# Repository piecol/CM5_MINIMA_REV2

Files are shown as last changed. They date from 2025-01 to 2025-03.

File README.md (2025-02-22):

# CM5 MINIMA REV2

## Introduction

The **CM5 MINIMA REV2** is a compact carrier board for the latest Raspberry Pi computing module 5.
It is designed for embedded applications, DIY electronics, and low-power computing projects. Unlike traditional desktop computers, the CM5 is a small, efficient system that integrates essential computing hardware onto a single board. Whether you're a hobbyist, developer, or engineer, this module provides a versatile platform for various applications, including IoT, automation, and custom hardware development.

If you're not familiar with Raspberry Pi or single-board computers (SBCs), think of the CM5 as a miniaturized computer that can handle tasks like data processing, networking, and hardware control, all while fitting in the palm of your hand. 
https://www.raspberrypi.com/products/compute-module-5/?variant=cm5-104032

Get to know the story behind the MINIMA on Hackster.io:

https://www.hackster.io/piecol/tiny-open-source-media-streamer-with-lorawan-what-a98a93

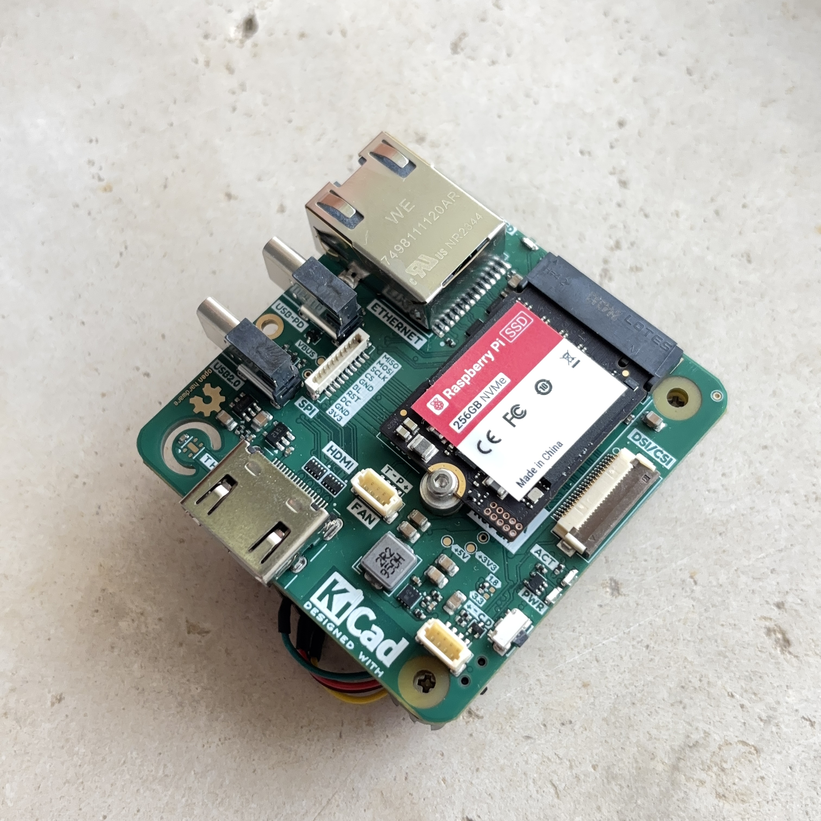
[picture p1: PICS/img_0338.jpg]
PCB_JLC


## Designed with KiCad

MINIMA was developed using KiCad, a powerful open-source Electronic Design Automation (EDA) tool. KiCad enables designers to create high-quality PCB layouts and schematics while maintaining full control over their hardware designs. By leveraging open-source tools like KiCad, the CM5 MINIMA REV2 embraces accessibility, collaboration, and innovation in hardware development.
It is also certified by the Open Source Hardware Association: https://certification.oshwa.org/it000020.html

## Key Features

- **USB-C Power Delivery (PD):** Supports power negotiation for efficient energy use.
- **USB 2.0 Ports:** Connect peripherals such as keyboards, mice, and external storage.
- **Gigabit Ethernet:** High-speed wired networking with a low-profile cutout magjack.
- **HDMI Port:** Output video to external displays for media playback or interface applications.
- **M.2 M Key Slot:** Supports 2230 SSDs for fast storage expansion.
- **CSI/DSI Connector:** Attach camera modules or displays for vision-based applications.
- **SHTC3 Sensirion Sensor:** Built-in temperature and humidity monitoring.
- **I2C Connector (3.3V only):** Connect low-power sensors and communication modules.
- **SPI Connector:** Supports high-speed communication with other devices.
- **Fan Connector:** Optional cooling support for high-performance applications.
- **Status LEDs:** Visual indicators for power and system activity.
- **Compact Size:** Measuring only **5.4 × 5.7 cm**, ideal for space-constrained projects.

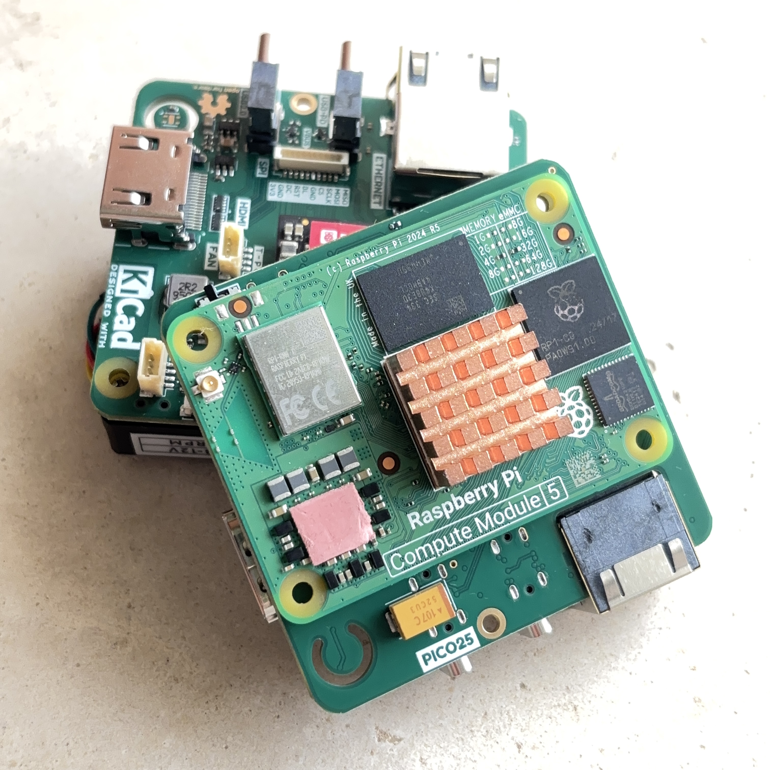
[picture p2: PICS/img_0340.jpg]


## Schematics

[PDF SCHEMATICS](https://github.com/piecol/CM5_MINIMA_REV2/blob/main/CM5_MINIMA_2.pdf)

## Getting Started

To use the **CM5 MINIMA REV2**, you'll need:

- A **USB-C power adapter** that supports Power Delivery (PD).
- A **display (HDMI)** and **input devices (USB keyboard/mouse)** for setup.
- A **network connection** (Ethernet or Wi-Fi via an external adapter if needed).

## Flashing OS

To flash an operating system (OS) to the CM5, use the switch located on the bottom of the board to enable flashing mode. It is equivalent to the "Fit nRPI_BOOT to J2 (disable eMMC Boot) on the IO board jumper." on the CM5 IO board.
Please refere to the official guidelines for further instructions:
https://www.raspberrypi.com/documentation/computers/compute-module.html#set-up-the-io-board

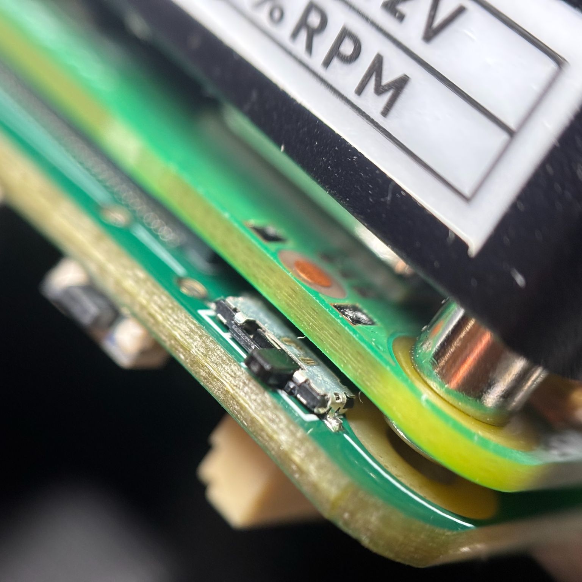
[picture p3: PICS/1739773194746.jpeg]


## Applications

- **IoT & Smart Devices:** Use sensors and network capabilities to create connected applications.
- **Home Automation:** Control and monitor home devices with minimal power consumption.
- **Embedded Systems:** Develop custom hardware solutions for industrial and consumer electronics.
- **Media Centers:** Play videos and manage digital content on an external display.
- **DIY Projects:** Ideal for makers and educators learning about electronics and programming.

## Conclusion

The **CM5 MINIMA REV2** is a powerful and flexible computing module that opens up endless possibilities for embedded computing and automation. Whether you're building a smart device, experimenting with sensors, or designing a networked system, this board provides the essential features you need in a compact, energy-efficient form factor.

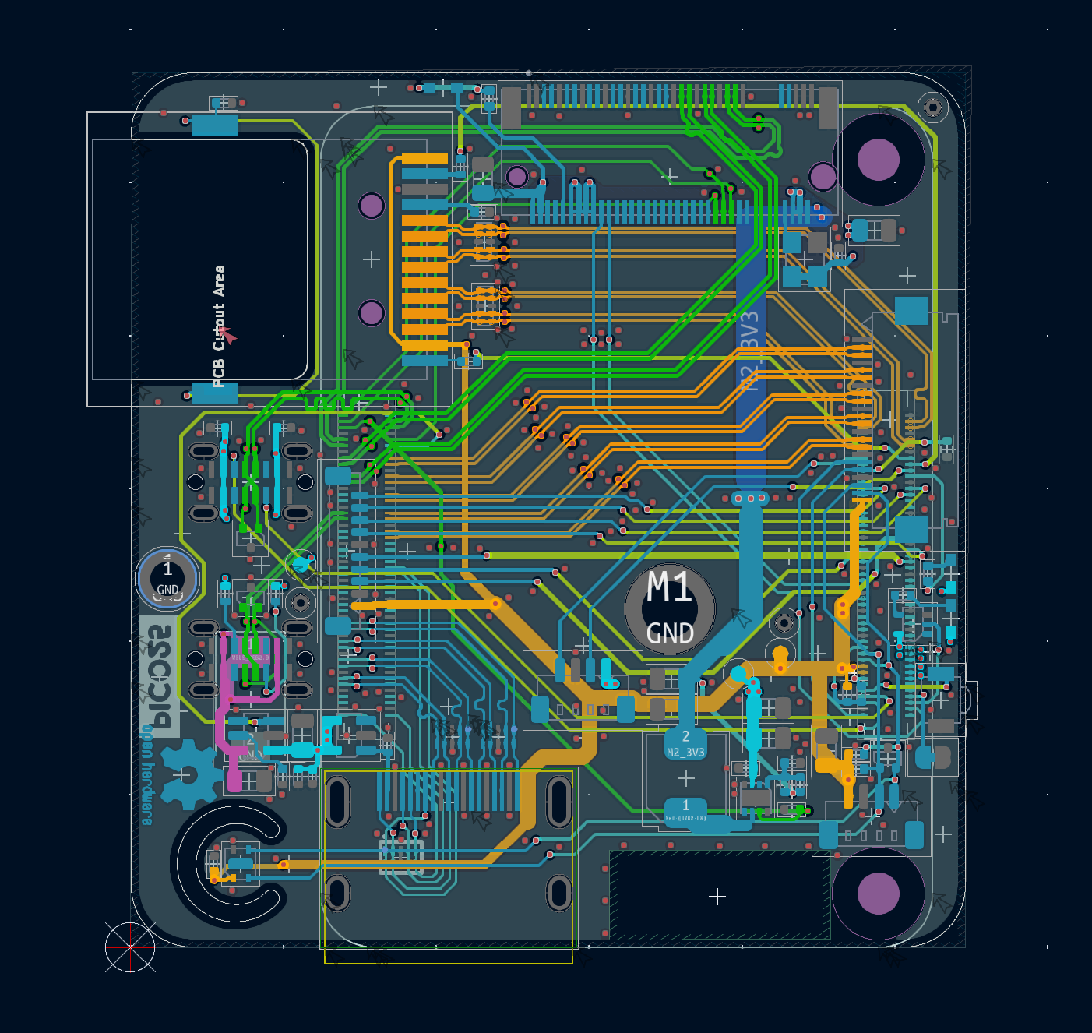
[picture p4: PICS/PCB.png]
PCB


## **Stackup**:
6L (SIG:PWR | GND | SIG-PWR | PWR | GND | SIG:PWR) 

### If you would like to support me:

"Buy Me A Coffee" (https://www.buymeacoffee.com/pierluigicj)

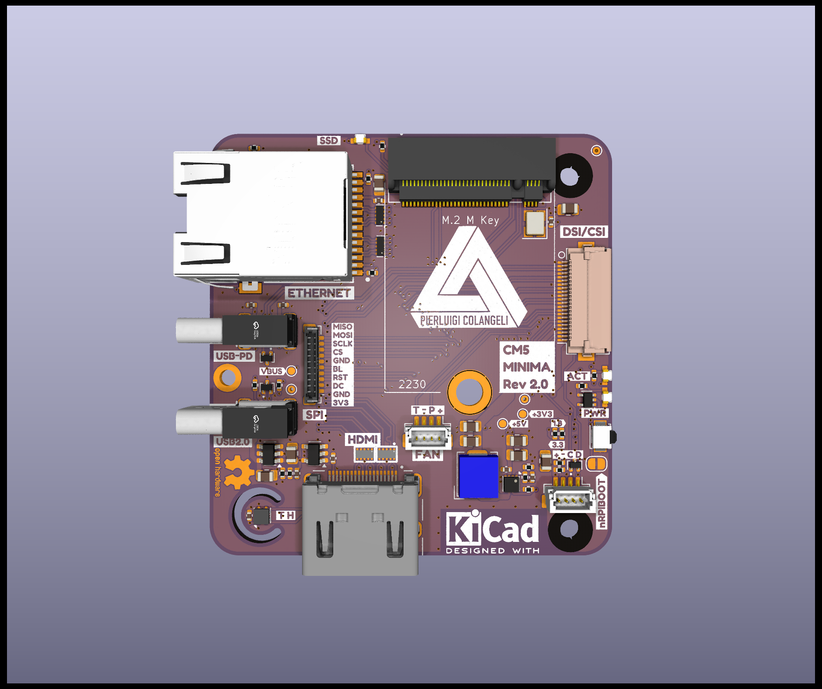
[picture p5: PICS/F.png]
F

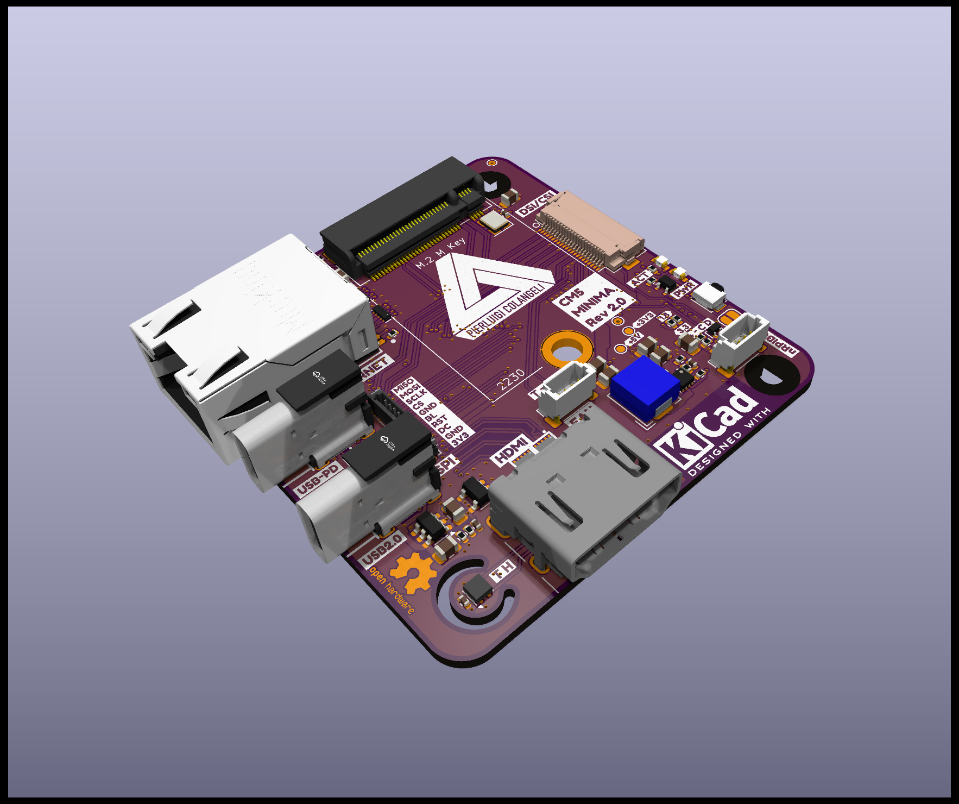
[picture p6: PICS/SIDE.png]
SIDE

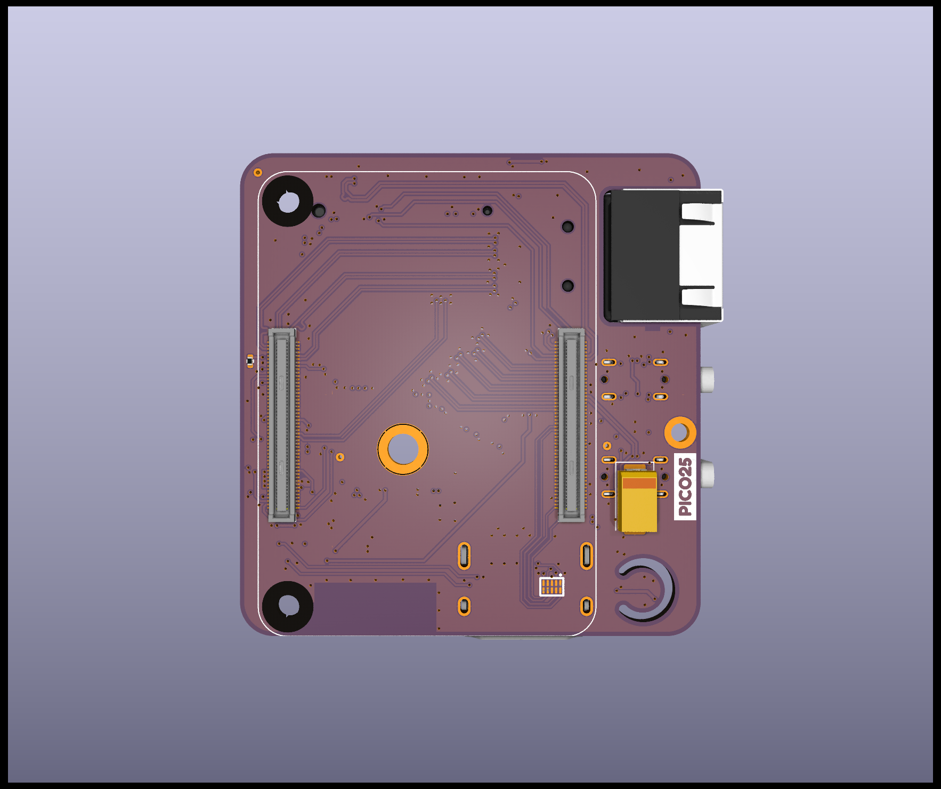
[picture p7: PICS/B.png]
B


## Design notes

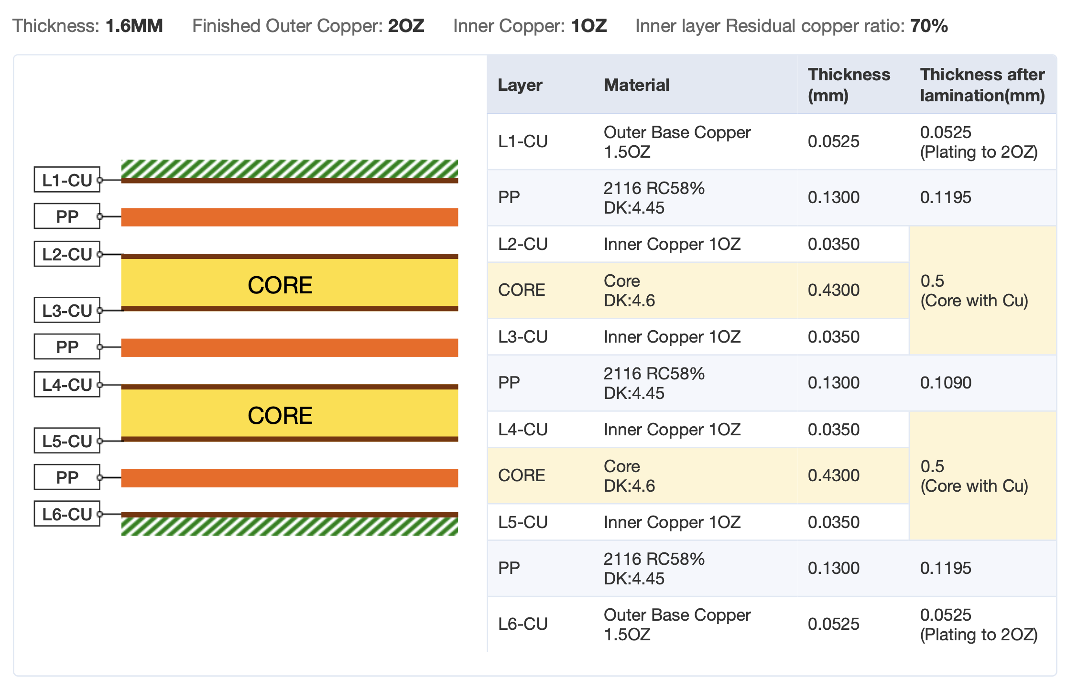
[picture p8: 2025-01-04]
PCBWay_6L_stackup.png

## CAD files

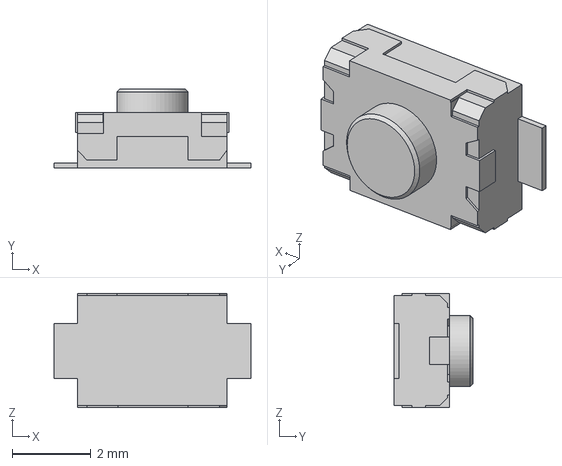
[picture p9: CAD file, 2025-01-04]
3d_lib/3x4x2 tact button.step
5.00 x 2.00 x 2.90 mm

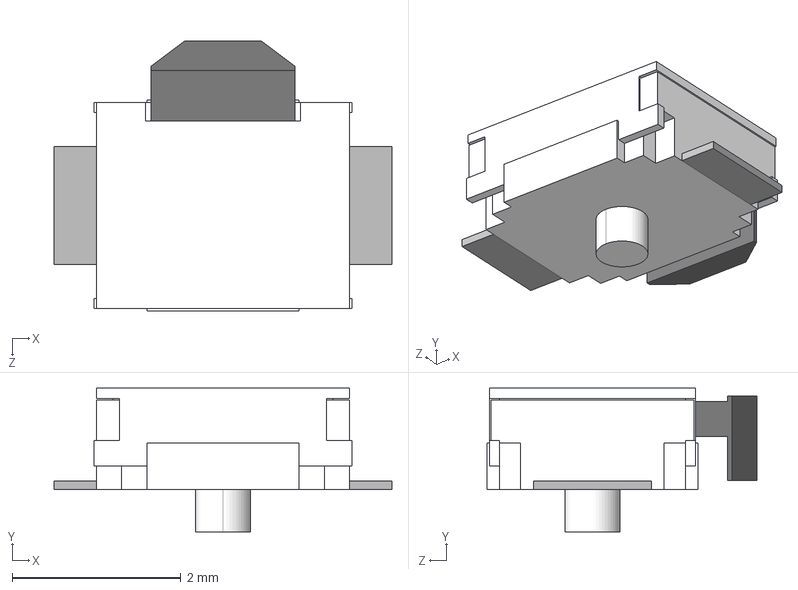
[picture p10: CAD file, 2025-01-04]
3d_lib/LIB_B3U-3000PM-B/B3U-3000PM-B/3D/B3U-3000PM-B.stp
4.00 x 1.70 x 3.20 mm

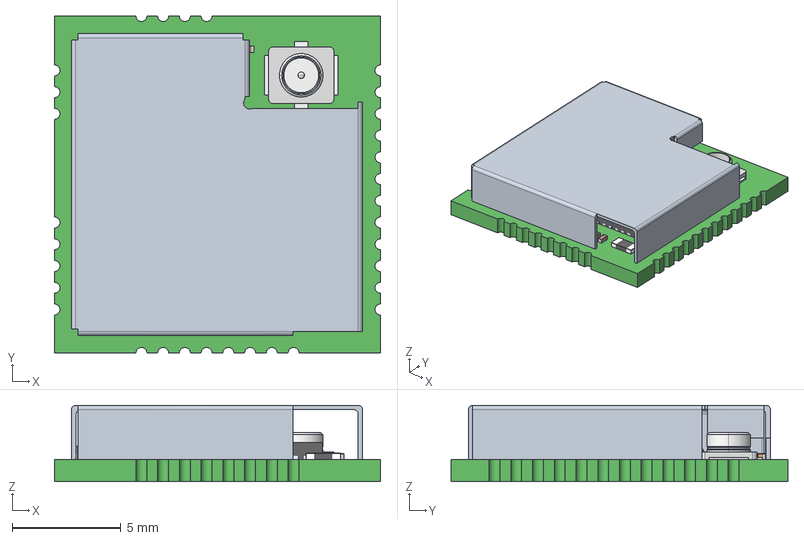
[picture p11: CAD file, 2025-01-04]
3d_lib/RAK3172--3DModel-STEP-100311.STEP
15.0 x 15.5 x 3.51 mm
0201_SMD_Capacitor x 36
Extruded
R0201 x 7
RES_1005-0402 x 3
QFN48_7x7
NT2016SA
C0402 x 4
crystal_rtf2012
D030A-そ敖裔

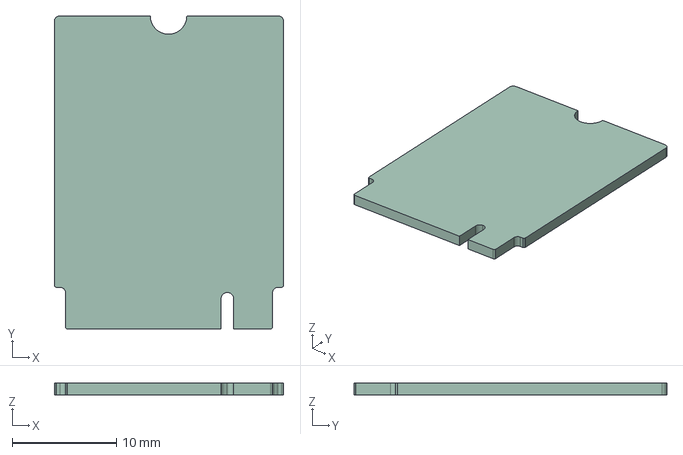
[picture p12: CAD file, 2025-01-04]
3d_lib/M.2-B.step
22.0 x 30.1 x 1.20 mm

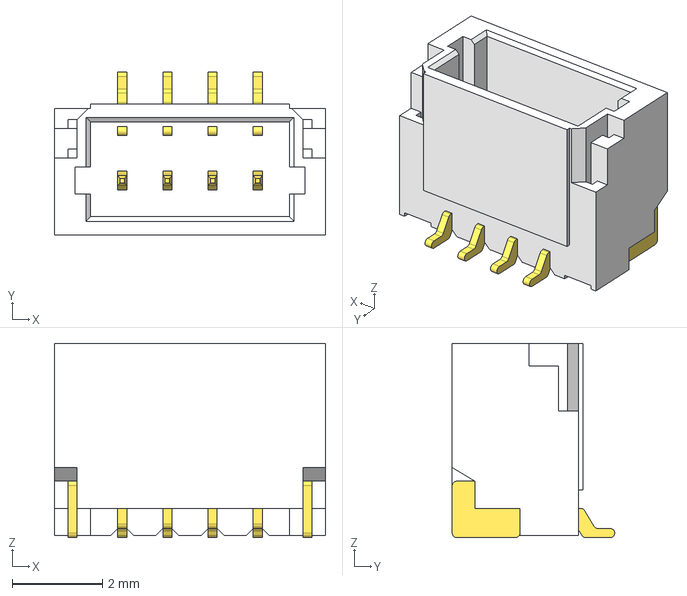
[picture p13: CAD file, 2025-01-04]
3d_lib/BM4B-SRSS-TB.step
6.00 x 3.60 x 4.30 mm

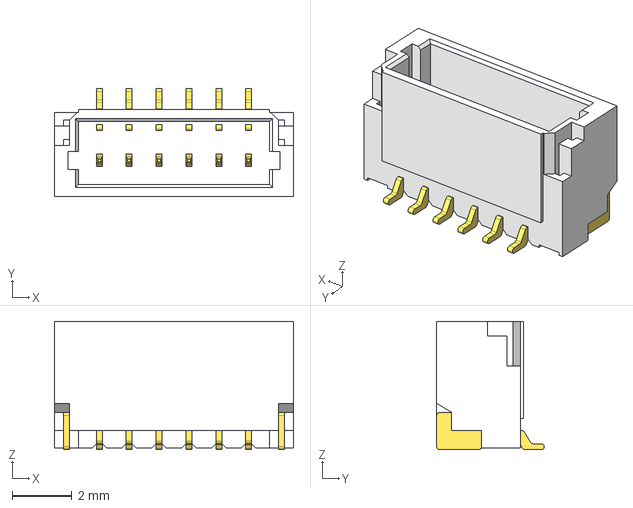
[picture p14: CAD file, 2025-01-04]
3d_lib/BM6B-SRSS-TB.step
8.00 x 3.60 x 4.30 mm

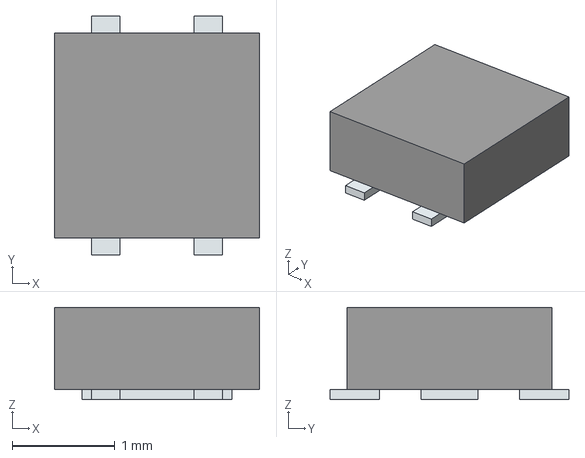
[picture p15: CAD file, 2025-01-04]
3d_lib/SHTC3-TR-10KS.stp
2.00 x 2.33 x 0.9 mm
Pins

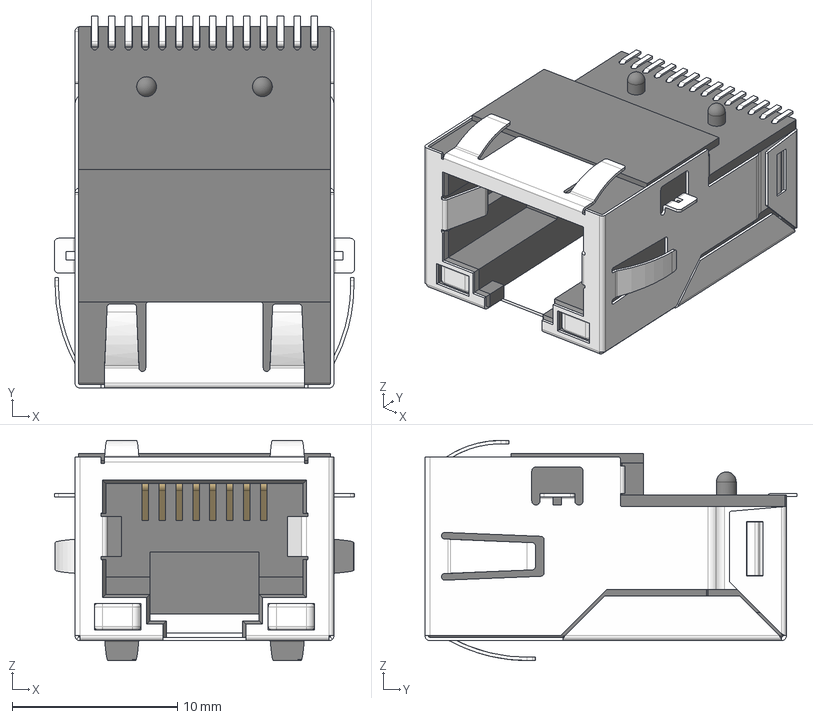
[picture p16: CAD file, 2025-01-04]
3d_lib/WE-RJ45LAN-7498111120AR (rev1).stp
18.1 x 22.5 x 13.3 mm
Shielding
Insulator x 3

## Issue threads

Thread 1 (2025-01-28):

PoE capabilities

jainavgohel, 2025-01-28:
Love this project, would be cool to see this support power over Ethernet so only one cable was needed for testing. This would cost a bit of board size but would be worth it to not need a second cable.

Additionally with PoE functionality it would make for a very appealing board in the home lab 10 in rack space.

piecol, 2025-01-28:
Thanks,

I'll consider the PoE, it's indeed a cool feature!

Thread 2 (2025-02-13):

HDMI Power-on Glitch

manuel-imboden, 2025-02-13:
Hi Pier

As discussed via email, I'm opening an issue so you can track this for a future revision:

When a HDMI monitor is connected, the MINIMA refuses to boot up again after booting once and shutting it down. As you have observed, this glitch is also present with Raspberry Pi I/O board and I have found at least one [report of a similar issue](https://forums.raspberrypi.com/viewtopic.php?t=381325).

In my testing, it only happened when the monitor and the MINIMA are on different power supplies (a wall adapter and a power bank for example) and when I am using a non-e-marked cable to power the MINIMA. Using a TB3 cable made the glitch disappear.

The reason remains elusive to me. Might be a capacitance problem as you have suggested, or something like a ground voltage offset that causes some reverse current to flow through the HDMI and triggers some protection.

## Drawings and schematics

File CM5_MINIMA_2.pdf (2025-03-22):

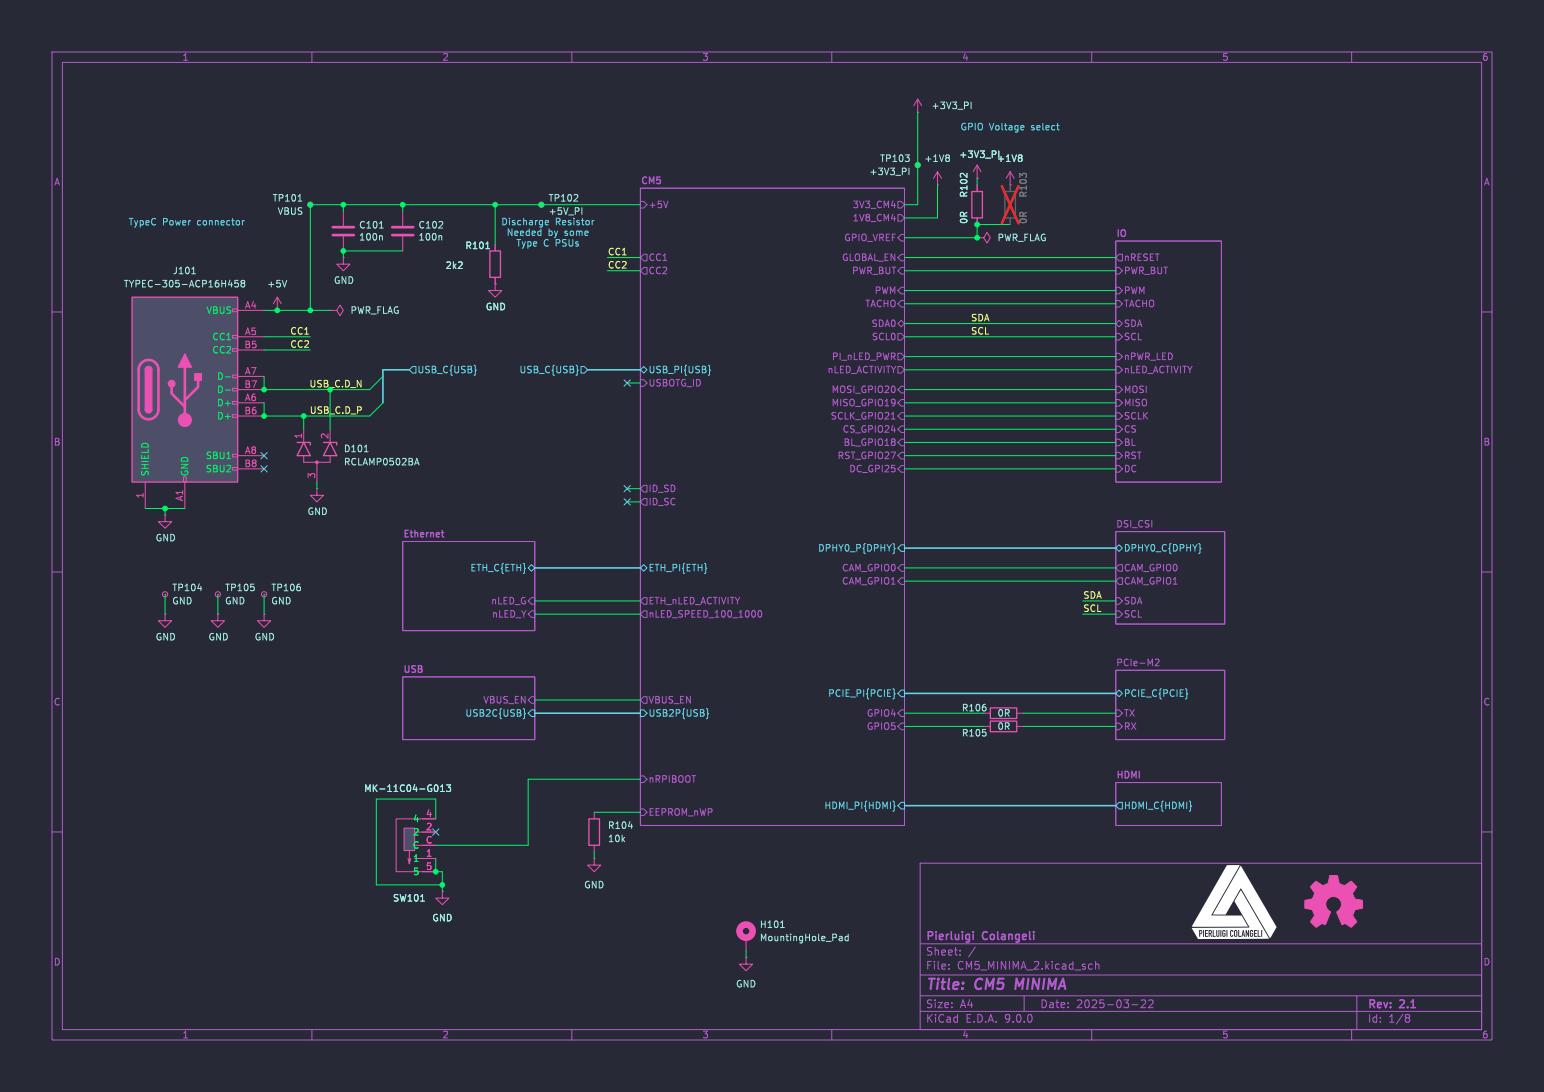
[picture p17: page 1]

PCIE_C{PCIE} PCIe-M2 HDMI_C{HDMI} HDMI USB_PI{USB} USBOTG_ID

SCL SDA DPHY0_C{DPHY} CAM_GPIO0 CAM_GPIO1 DSI_CSI ETH_C{ETH} nLED_Y

File: CM5_MINIMA_2.kicad_sch Sheet: / Pierluigi Colangeli

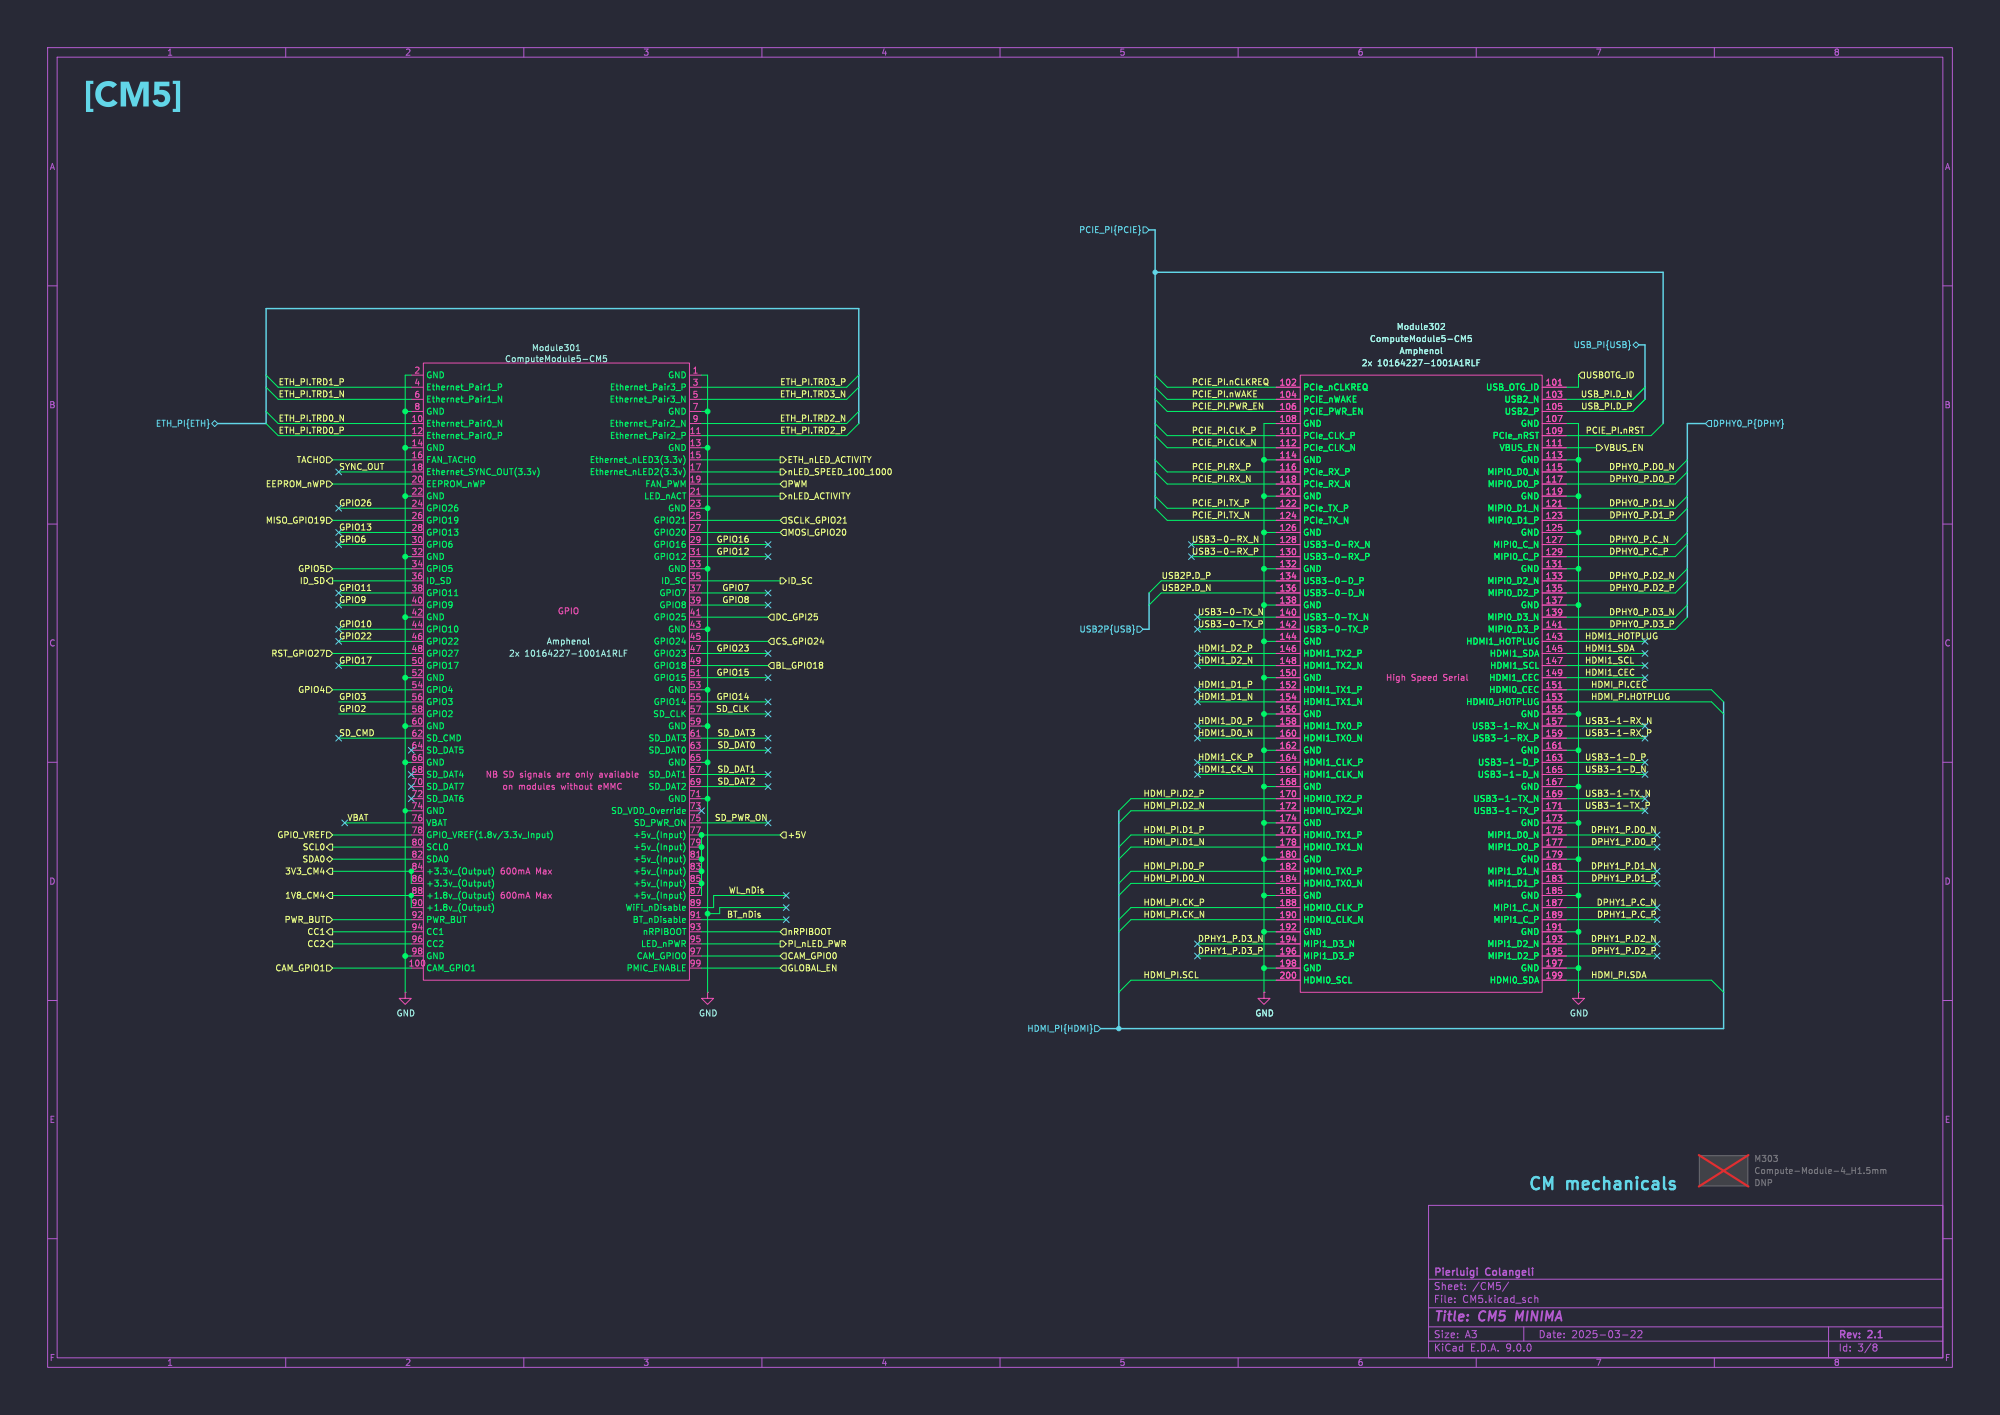
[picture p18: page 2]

GND 2 Ethernet_Pair1_P 4 Ethernet_Pair1_N 6 GND 8 Ethernet_Pair0_N 10 Ethernet_Pair0_P 12 GND 14 FAN_TACHO 16 Ethernet_SYNC_OUT(3.3v) 18 EEPROM_nWP 20 GND 22 GPIO26 24 GPIO19 26 GPIO13 28 GPIO6 30 GND 32 GPIO5 34
ID_SD 36 GPIO11 38 GPIO9 40 GND 42 GPIO10 44 GPIO22 46 GPIO27 48 GPIO17 50 GND 52 GPIO4 54 GPIO3 56 GPIO2 58 GND 60 SD_CMD 62 SD_DAT5 64 GND 66 SD_DAT4 68 SD_DAT7 70 SD_DAT6 72 GND 74 VBAT 76 GPIO_VREF(1.8v/3.3v_Input) 78 SCL0 80 SDA0 82 +3.3v_(Output) 84 +3.3v_(Output) 86 +1.8v_(Output) 88 +1.8v_(Output) 90 PWR_BUT 92 CC1 94 CC2 96 GND 98 CAM_GPIO1 100

on modules without eMMC GPIO

600mA Max 600mA Max NB SD signals are only available

File: CM5.kicad_sch Sheet: /CM5/ Pierluigi Colangeli

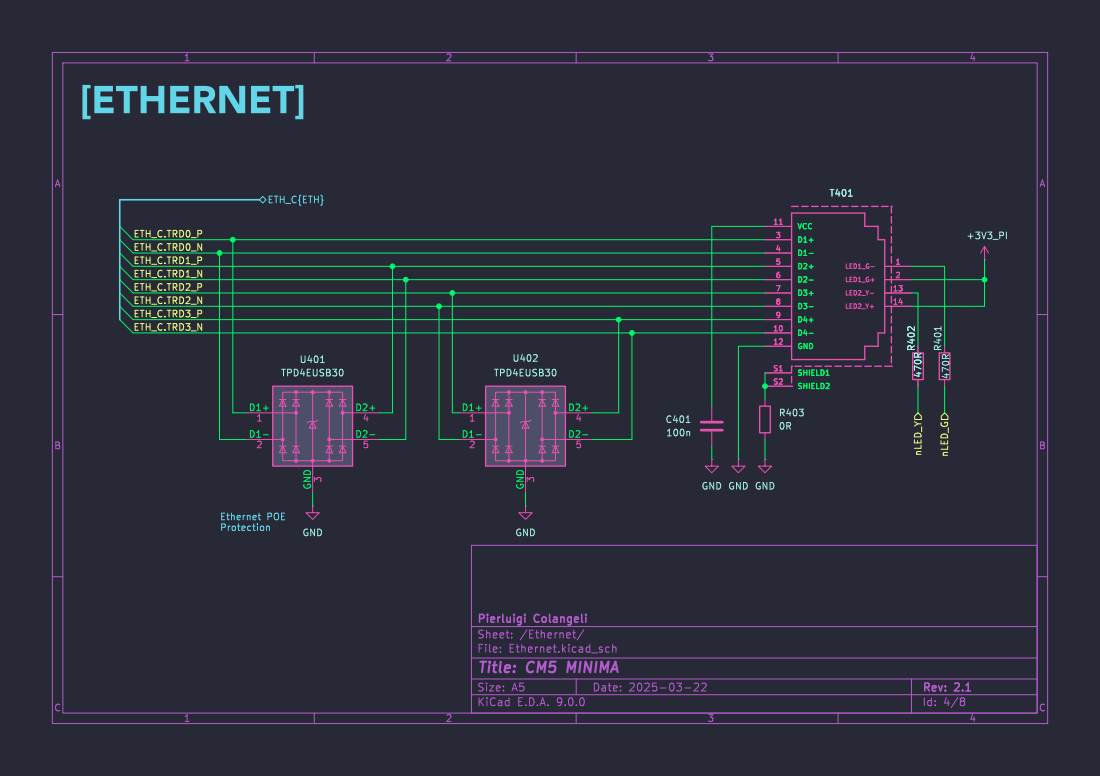
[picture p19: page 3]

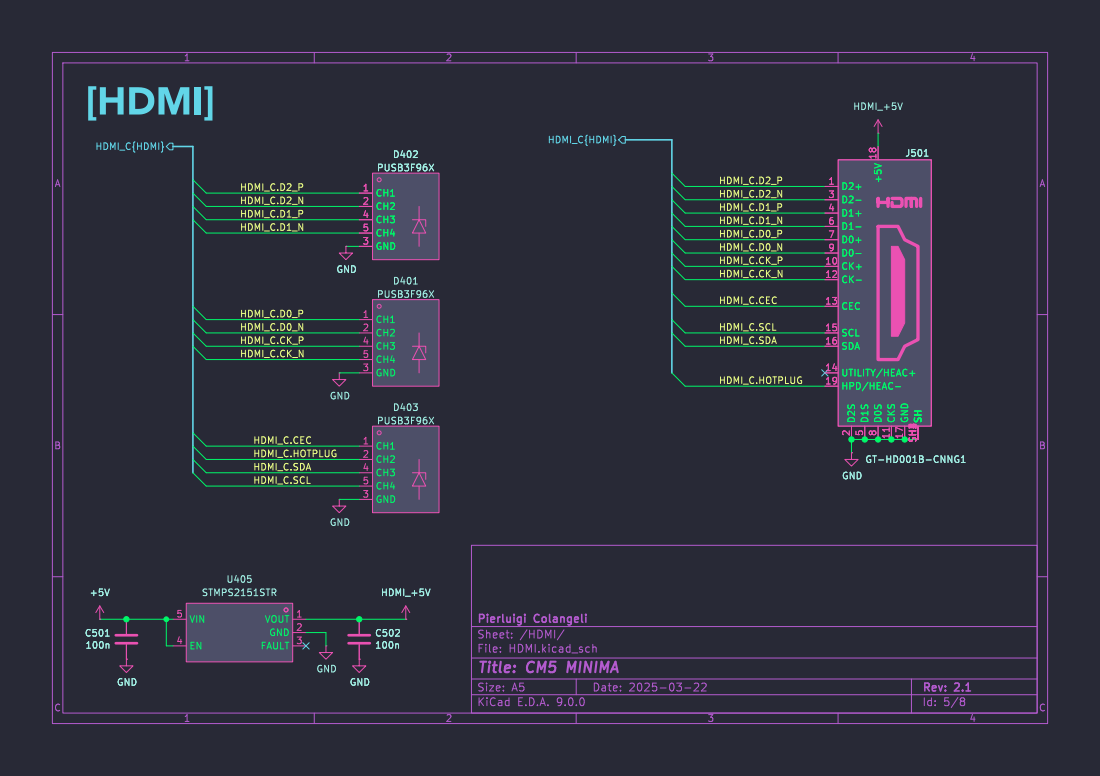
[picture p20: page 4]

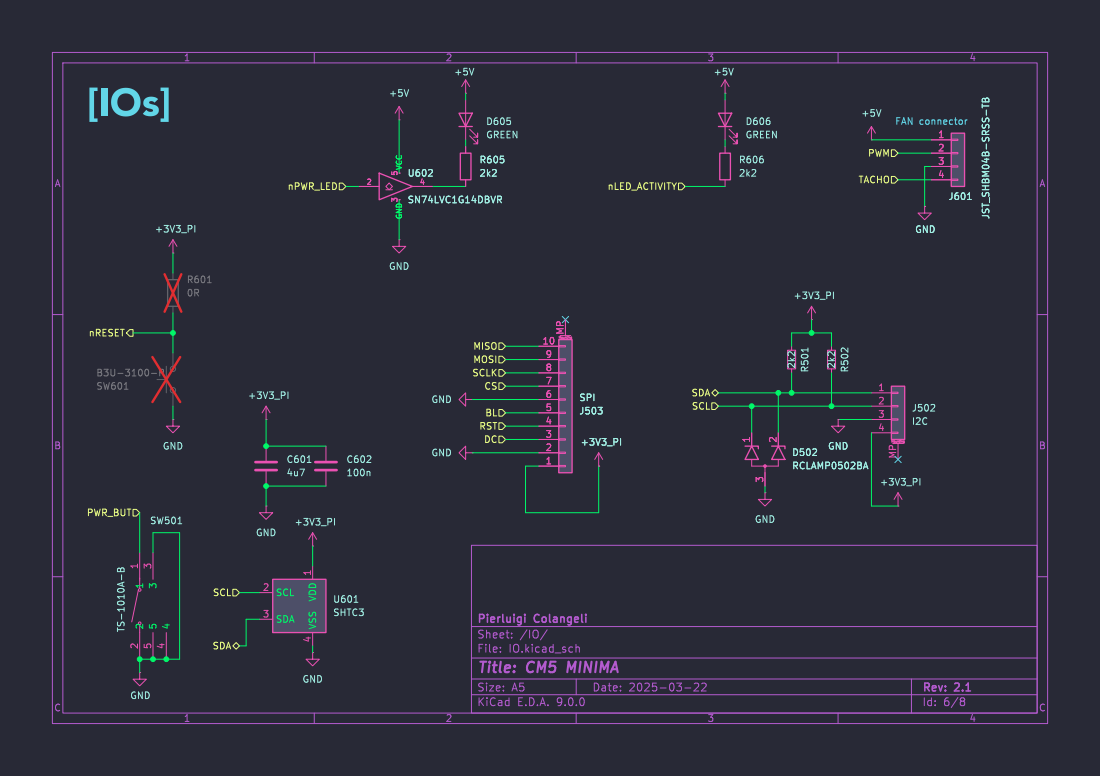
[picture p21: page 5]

2 | Mounting 1

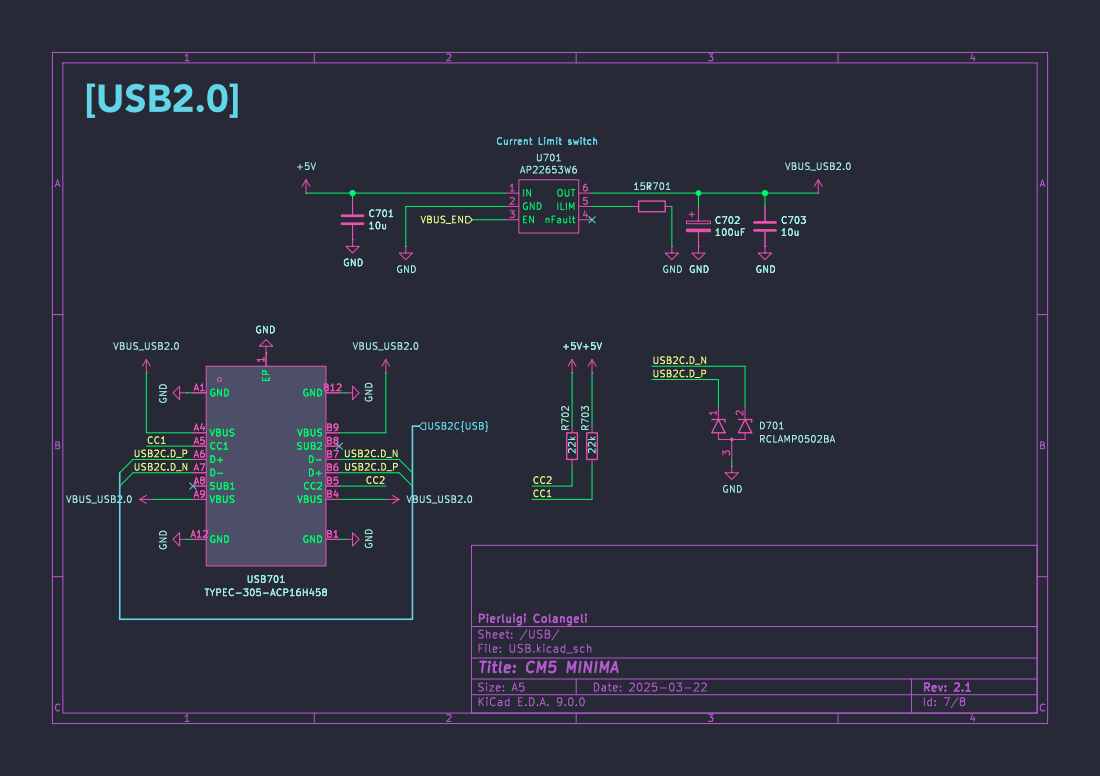
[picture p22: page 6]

File: USB.kicad_sch Sheet: /USB/ Pierluigi Colangeli C701
USB2C{USB} VBUS_EN
10uGND

1 GNDB12 VBUS B9 SUB2 B8 D- B7 D+ B6 CC2 B5 VBUS B4 GND B1 GND

1 GNDB12 VBUS B9 SUB2 B8 D- B7 D+ B6 CC2 B5 VBUS B4 GND B1 USB701 TYPEC-305-ACP16H458

2 D701 RCLAMP0502BA GND GND GND GND

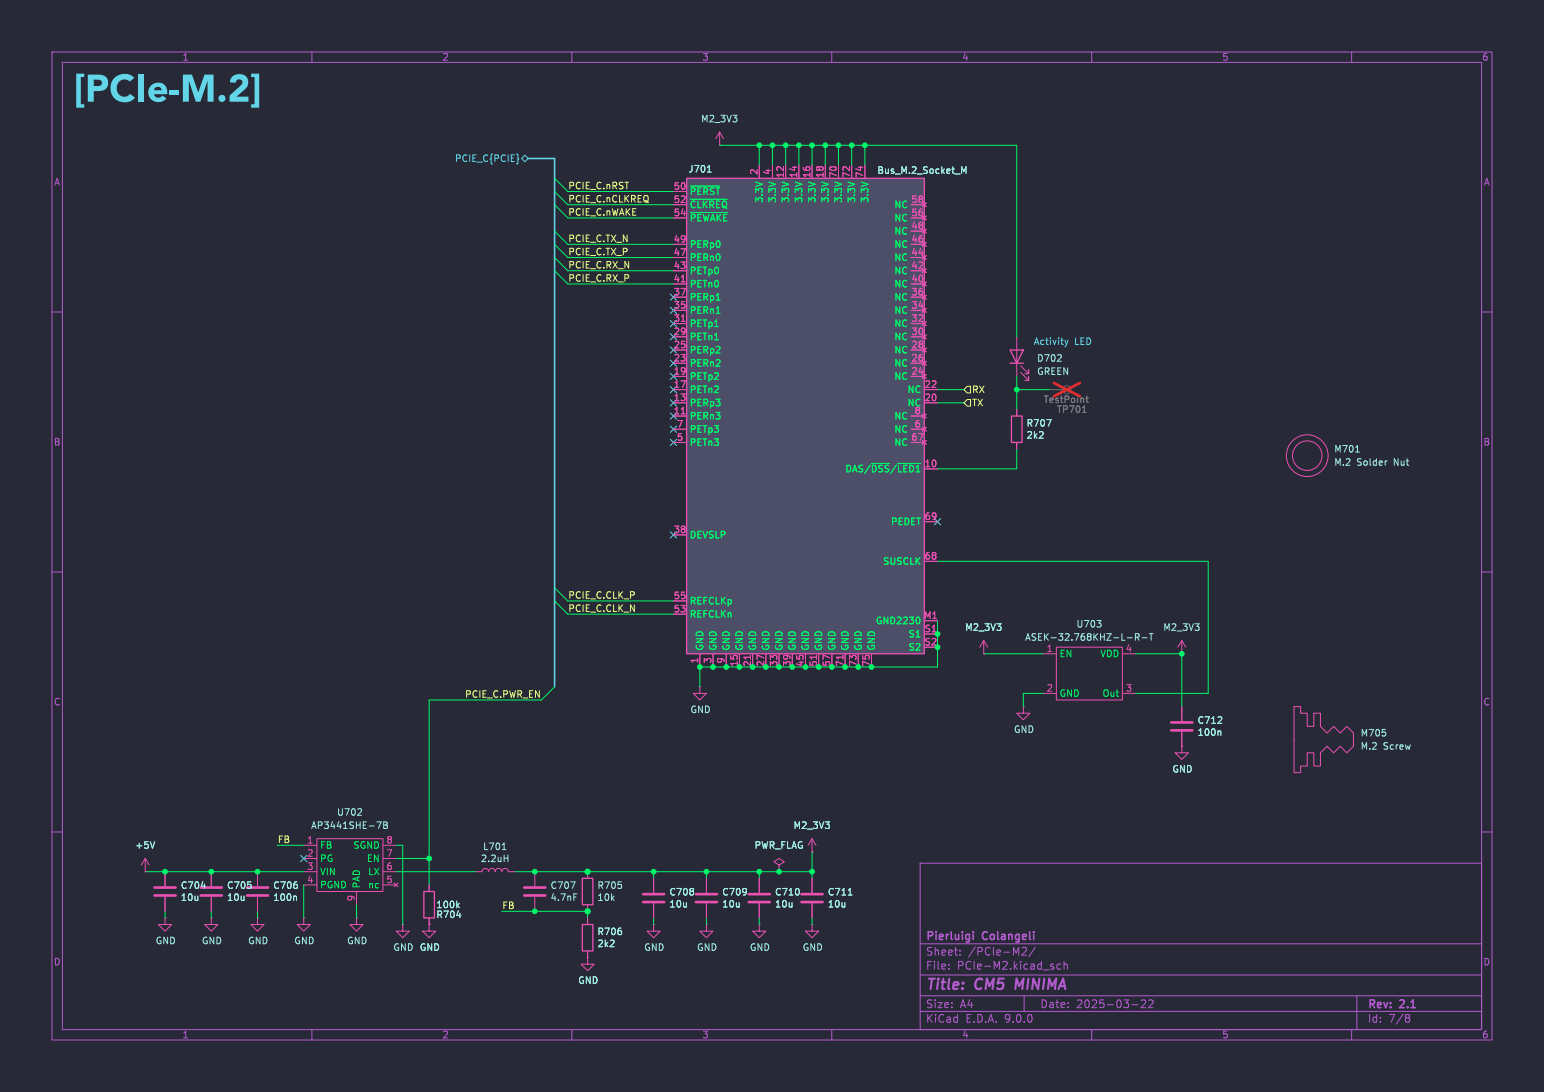
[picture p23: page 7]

4 GND 33 3.3V 12 GND 39 3.3V 14 GND 45 3.3V 16 GND 51 3.3V 18 GND 57 3.3V 70 GND 71 3.3V 72 GND 73 3.3V 74 GND 75 NC 58 NC 56 NC 48 NC 46 NC 44 NC 42 NC 40 NC 36 NC 34 NC 32 NC 30 NC 28 NC 26 NC 24 NC 8 NC 6 NC 67 NC 22 NC 20 DAS/~{DSS}/~{LED1} 10 PEDET 69 SUSCLK 68 GND2230 M1 S1 S1 S2 S2 C704

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

File: PCIe-M2.kicad_sch Sheet: /PCIe-M2/ Pierluigi Colangeli GND

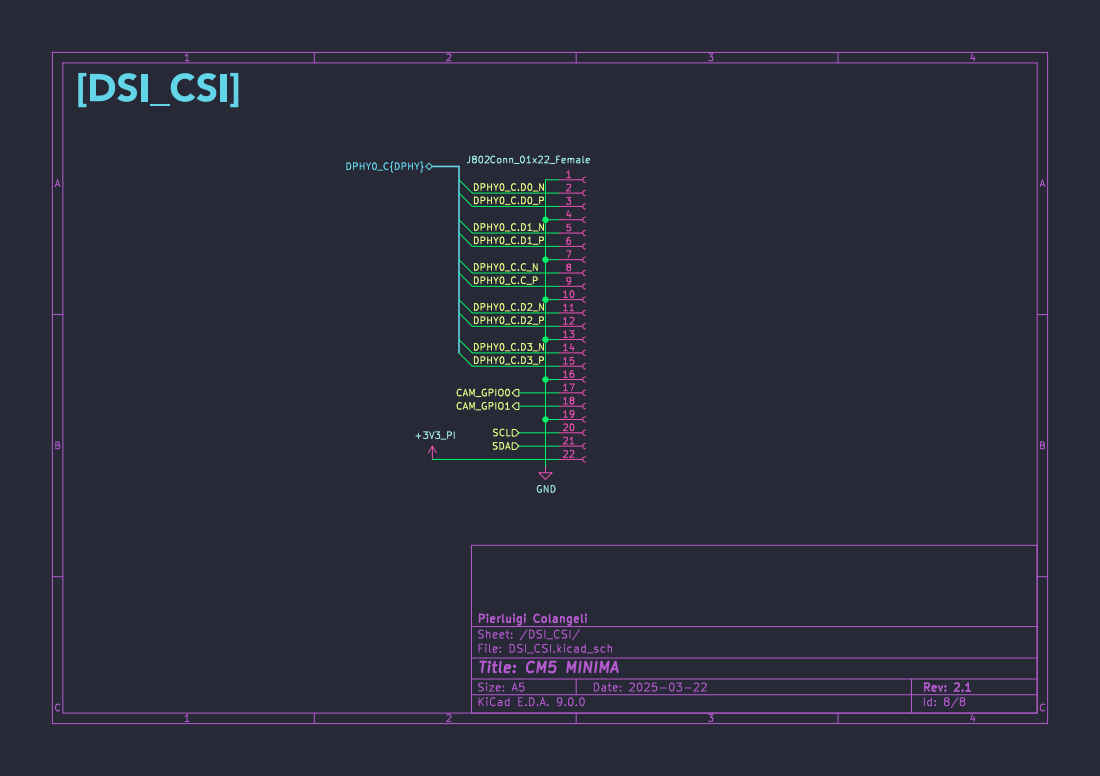
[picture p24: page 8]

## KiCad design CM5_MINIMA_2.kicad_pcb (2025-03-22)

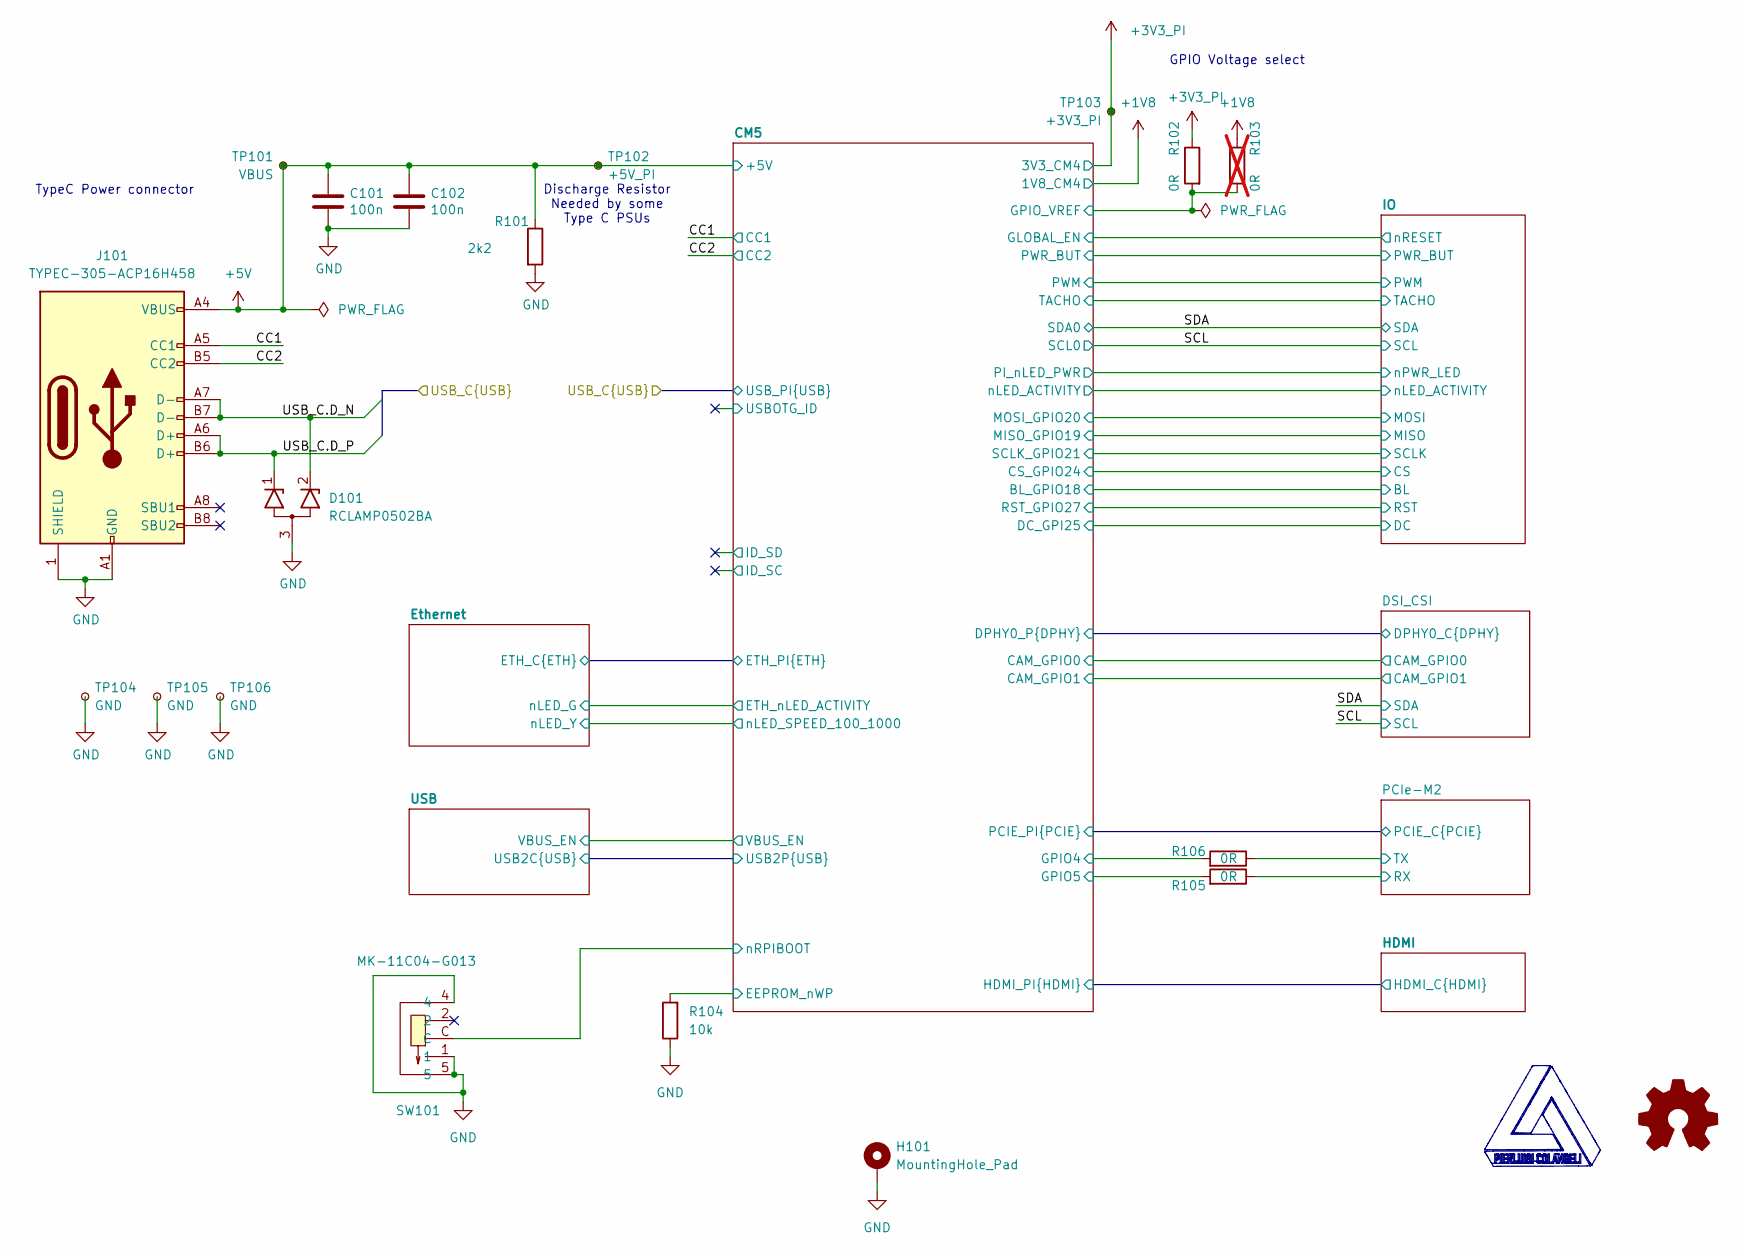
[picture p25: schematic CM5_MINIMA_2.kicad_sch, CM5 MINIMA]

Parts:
C101, C102: 100n; C_0402_1005Metric; Part Description 0.1uF 10% 16V Ceramic Capacitor X7R 040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
D101: RCLAMP0502BA; SOT-416
H101: MountingHole_Pad; MountingHole_2.2mm_M2_DIN965_Pad_TopBottom
J101: TYPEC-305-ACP16H458; USB-C-SMD_TYPEC-305-ACP16H458; Part Description USBC USB2 data and power connector
R101: 2k2; R_0402_1005Metric
R102, R105, R106: 0R; R_0402_1005Metric; Part Description Resistor 0R M2012 5%
R103: 0R; R_0402_1005Metric; not fitted
R104: 10k; R_0402_1005Metric
SW101: MK-11C04-G013; SW-SMD_MK-11C04-G013; LCSC Part C778185
TP101: VBUS; TestPoint_Pad_D1.0mm
TP102: +5V_PI; TestPoint_Pad_D1.0mm
TP103: +3V3_PI; TestPoint_Pad_D1.0mm
TP104, TP105, TP106: GND; TestPoint_THTPad_D1.0mm_Drill0.5mm

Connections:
+1V8: R103.1; also elsewhere on the board
+3V3_PI: R102.1, TP103.1; also elsewhere on the board
+5V: C101.1, C102.1, J101.A4 (VBUS), J101.A9 (VBUS), J101.B4 (VBUS), J101.B9 (VBUS), R101.1, TP101.1, TP102.1; also elsewhere on the board
/CC1: J101.A5 (CC1); also elsewhere on the board
/CC2: J101.B5 (CC2); also elsewhere on the board
/CM5/EEPROM_nWP: R104.2; also elsewhere on the board
/CM5/GPIO4: R106.2; also elsewhere on the board
/CM5/GPIO5: R105.2; also elsewhere on the board
/CM5/GPIO_VREF: R102.2, R103.2; also elsewhere on the board
/CM5/nRPIBOOT: SW101.C; also elsewhere on the board
/PCIe-M2/RX: R105.1; also elsewhere on the board
/PCIe-M2/TX: R106.1; also elsewhere on the board
/USB_C.D_N: D101.2 (K2), J101.A7 (D-), J101.B7 (D-); also elsewhere on the board
/USB_C.D_P: D101.1 (K1), J101.A6 (D+), J101.B6 (D+); also elsewhere on the board
GND: C101.2, C102.2, D101.3 (A), H101.1, J101.1 (SHIELD), J101.A1 (GND), J101.A12 (GND), J101.B1 (GND), J101.B12 (GND), R101.2, R104.1, SW101.1, SW101.4, SW101.5, TP104.1, TP105.1, TP106.1; also elsewhere on the board

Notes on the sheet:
GPIO Voltage select
TypeC Power connector
Discharge Resistor Needed by some Type C PSUs

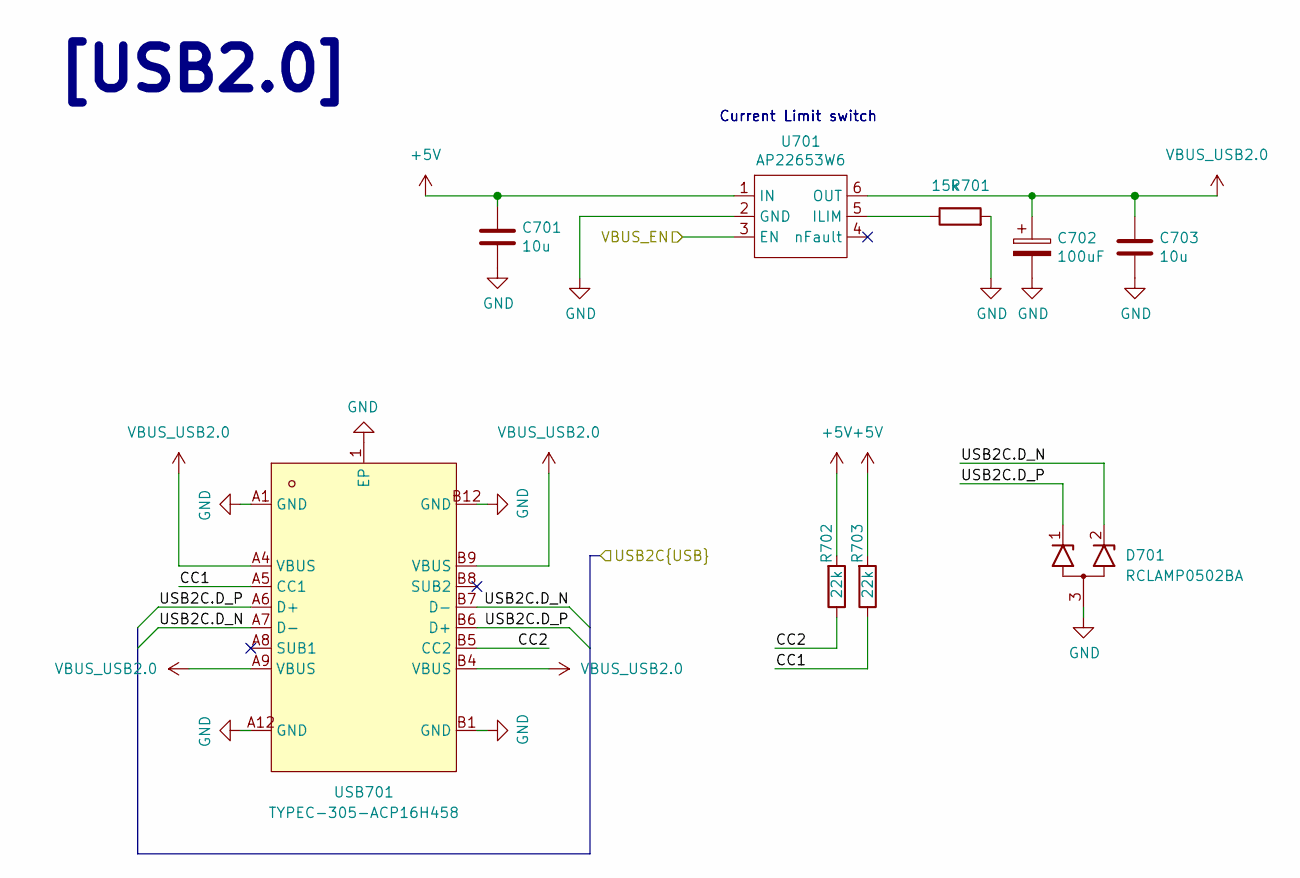
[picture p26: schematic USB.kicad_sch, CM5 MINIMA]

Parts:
C701, C703: 10u; C_0805_2012Metric; Part Description 10uF 10% 10V Ceramic Capacitor X7R 0805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
C702: 100uF; CP_EIA-7343-31_Kemet-D; Part Description Capacitor, SP-Cap, 100u, 6.3V, 15mR ESR
D701: RCLAMP0502BA; SOT-416
R701: 15k; R_0402_1005Metric; Part Description Resistor 15K M1005 1% 63mW
R702, R703: 22k; R_0402_1005Metric
U701: AP22653W6; SOT-23-6; Part Description Power Switch/Driver 1:1 P-Channel 2.1A 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
USB701: TYPEC-305-ACP16H458; USB-C-SMD_TYPEC-305-ACP16H458; LCSC Part C5454943

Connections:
+5V: C701.1, R702.2, R703.2, U701.1 (IN); also elsewhere on the board
/CM5/USB2P.D_N: D701.2 (K2), USB701.A7 (D-), USB701.B7 (D-); also elsewhere on the board
/CM5/USB2P.D_P: D701.1 (K1), USB701.A6 (D+), USB701.B6 (D+); also elsewhere on the board
/CM5/VBUS_EN: U701.3 (EN); also elsewhere on the board
/USB/CC1: R703.1, USB701.A5 (CC1)
/USB/CC2: R702.1, USB701.B5 (CC2)
GND: C701.2, C702.2, C703.2, D701.3 (A), R701.2, U701.2 (GND), USB701.1 (EP), USB701.A1 (GND), USB701.A12 (GND), USB701.B1 (GND), USB701.B12 (GND); also elsewhere on the board
unnamed: R701.1, U701.5 (ILIM)
VBUS_USB2.0: C702.1, C703.1, U701.6 (OUT), USB701.A4 (VBUS), USB701.A9 (VBUS), USB701.B4 (VBUS), USB701.B9 (VBUS)

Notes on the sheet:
[USB2.0]
Current Limit switch

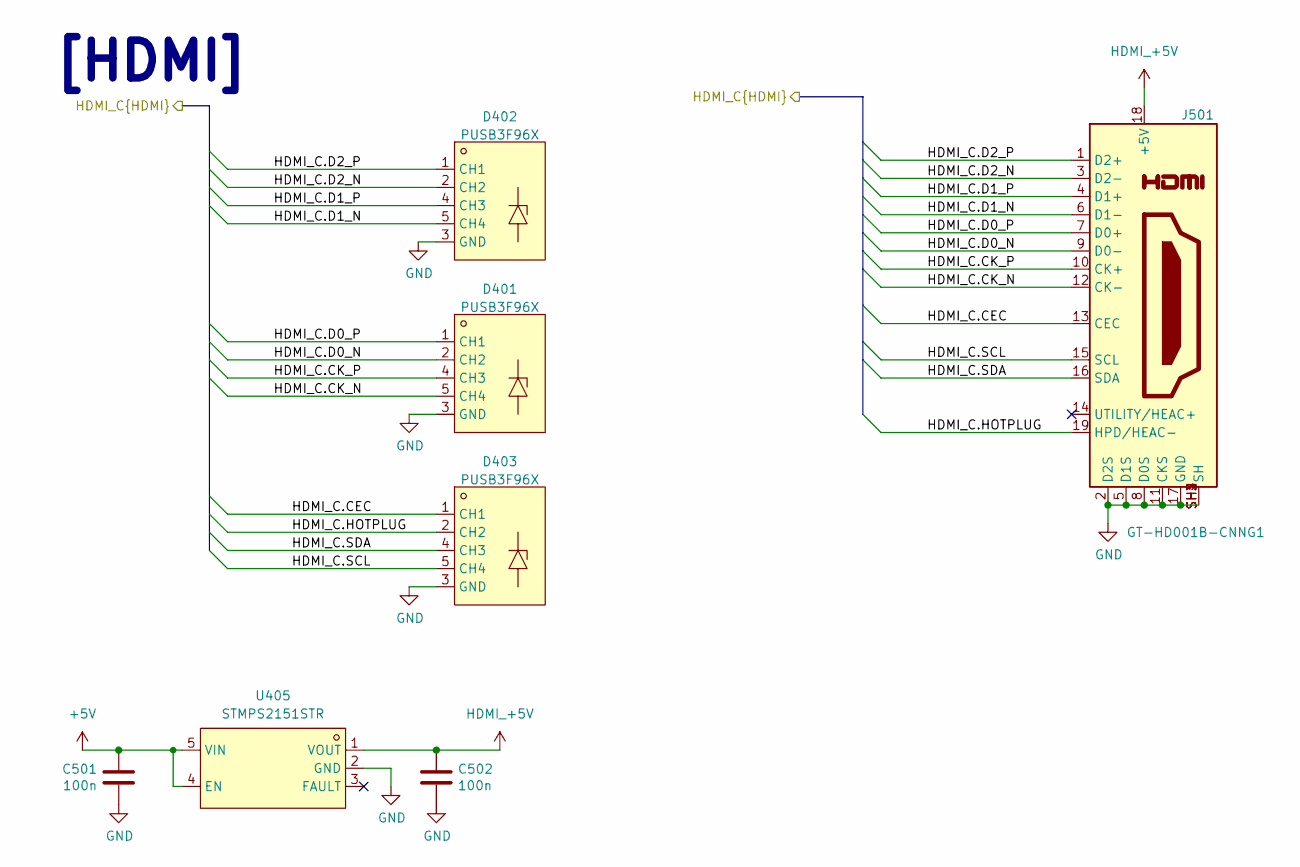
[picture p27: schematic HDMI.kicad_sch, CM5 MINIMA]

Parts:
C501, C502: 100n; C_0402_1005Metric; Part Description 0.1uF 10% 16V Ceramic Capacitor X7R 040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
D401, D402, D403: PUSB3F96X; DFN2510A-10_L2.5-W1.0-P0.50-BL; LCSC Part C478121
J501: GT-HD001B-CNNG1; EDAC 690-019-298-412; Part Description HDMI Connector, Right Angle, 19 Contact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
U405: STMPS2151STR; SOT-23-5; LCSC Part C135998

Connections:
+5V: C501.1, U405.4 (EN), U405.5 (VIN); also elsewhere on the board
/CM5/HDMI_PI.CEC: D403.1 (CH1), D403.10 (NC), J501.13 (CEC); also elsewhere on the board
/CM5/HDMI_PI.CK_N: D401.5 (CH4), D401.6 (NC), J501.12 (CK-); also elsewhere on the board
/CM5/HDMI_PI.CK_P: D401.4 (CH3), D401.7 (NC), J501.10 (CK+); also elsewhere on the board
/CM5/HDMI_PI.D0_N: D401.2 (CH2), D401.9 (NC), J501.9 (D0-); also elsewhere on the board
/CM5/HDMI_PI.D0_P: D401.1 (CH1), D401.10 (NC), J501.7 (D0+); also elsewhere on the board
/CM5/HDMI_PI.D1_N: D402.5 (CH4), D402.6 (NC), J501.6 (D1-); also elsewhere on the board
/CM5/HDMI_PI.D1_P: D402.4 (CH3), D402.7 (NC), J501.4 (D1+); also elsewhere on the board
/CM5/HDMI_PI.D2_N: D402.2 (CH2), D402.9 (NC), J501.3 (D2-); also elsewhere on the board
/CM5/HDMI_PI.D2_P: D402.1 (CH1), D402.10 (NC), J501.1 (D2+); also elsewhere on the board
/CM5/HDMI_PI.HOTPLUG: D403.2 (CH2), D403.9 (NC), J501.19 (HPD/HEAC-); also elsewhere on the board
/CM5/HDMI_PI.SCL: D403.5 (CH4), D403.6 (NC), J501.15 (SCL); also elsewhere on the board
/CM5/HDMI_PI.SDA: D403.4 (CH3), D403.7 (NC), J501.16 (SDA); also elsewhere on the board
GND: C501.2, C502.2, D401.3 (GND), D401.8 (GND), D402.3 (GND), D402.8 (GND), D403.3 (GND), D403.8 (GND), J501.2 (D2S), J501.5 (D1S), J501.8 (D0S), J501.11 (CKS), J501.17 (GND), J501.SH1 (SH), J501.SH2 (SH), J501.SH3 (SH), J501.SH4 (SH), U405.2 (GND); also elsewhere on the board
HDMI_+5V: C502.1, J501.18 (+5V), U405.1 (VOUT)

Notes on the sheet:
[HDMI]

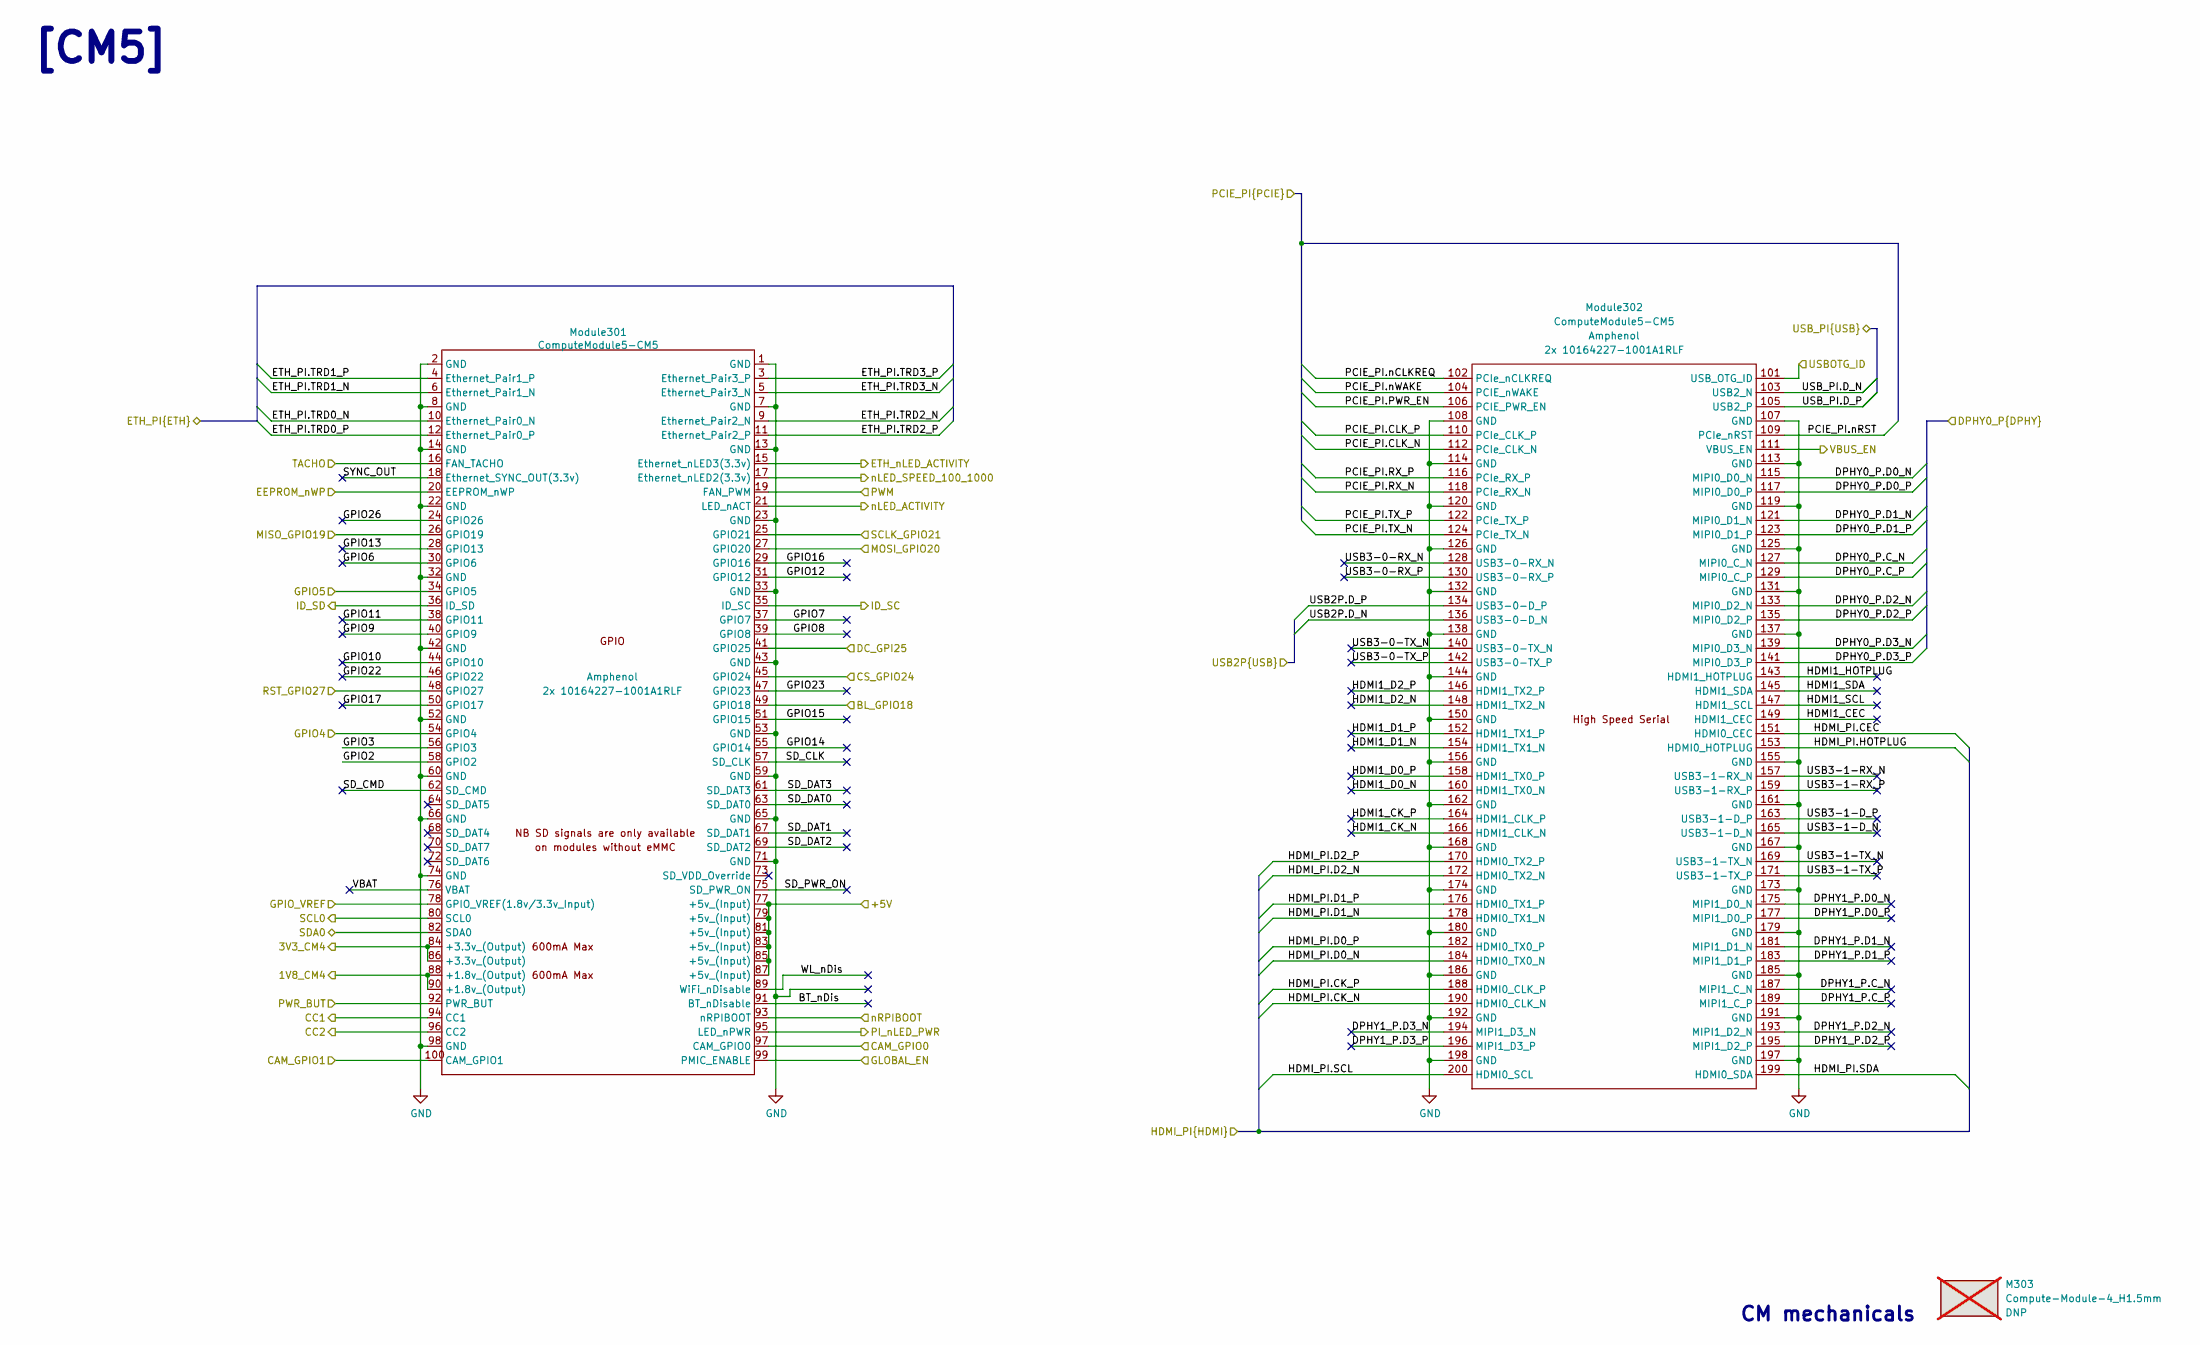
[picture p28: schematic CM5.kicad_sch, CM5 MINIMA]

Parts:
M303: Compute-Module-4_H1.5mm; MPN SC0294; not fitted
Module301: ComputeModule5-CM5; Raspberry-Pi-5-Compute-Module_GPIO; Part Description 100 Position Connector Receptacle, Cent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
Module302: ComputeModule5-CM5; Raspberry-Pi-5-Compute-Module_HSS; Part Description 100 Position Connector Receptacle, Cent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

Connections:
+1V8: Module301.88 (+1.8v_(Output)), Module301.90 (+1.8v_(Output)); also elsewhere on the board
+3V3_PI: Module301.84 (+3.3v_(Output)), Module301.86 (+3.3v_(Output)); also elsewhere on the board
+5V: Module301.77 (+5v_(Input)), Module301.79 (+5v_(Input)), Module301.81 (+5v_(Input)), Module301.83 (+5v_(Input)), Module301.85 (+5v_(Input)), Module301.87 (+5v_(Input)); also elsewhere on the board
/CC1: Module301.94 (CC1); also elsewhere on the board
/CC2: Module301.96 (CC2); also elsewhere on the board
/CM5/BL_GPIO18: Module301.49 (GPIO18); also elsewhere on the board
/CM5/BT_nDis: Module301.91 (BT_nDisable)
/CM5/CAM_GPIO0: Module301.97 (CAM_GPIO0); also elsewhere on the board
/CM5/CAM_GPIO1: Module301.100 (CAM_GPIO1); also elsewhere on the board
/CM5/CS_GPIO24: Module301.45 (GPIO24); also elsewhere on the board
/CM5/DC_GPI25: Module301.41 (GPIO25); also elsewhere on the board
/CM5/DPHY0_P.C_N: Module302.127 (MIPI0_C_N); also elsewhere on the board
/CM5/DPHY0_P.C_P: Module302.129 (MIPI0_C_P); also elsewhere on the board
/CM5/DPHY0_P.D0_N: Module302.115 (MIPI0_D0_N); also elsewhere on the board
/CM5/DPHY0_P.D0_P: Module302.117 (MIPI0_D0_P); also elsewhere on the board
/CM5/DPHY0_P.D1_N: Module302.121 (MIPI0_D1_N); also elsewhere on the board
/CM5/DPHY0_P.D1_P: Module302.123 (MIPI0_D1_P); also elsewhere on the board
/CM5/DPHY0_P.D2_N: Module302.133 (MIPI0_D2_N); also elsewhere on the board
/CM5/DPHY0_P.D2_P: Module302.135 (MIPI0_D2_P); also elsewhere on the board
/CM5/DPHY0_P.D3_N: Module302.139 (MIPI0_D3_N); also elsewhere on the board
/CM5/DPHY0_P.D3_P: Module302.141 (MIPI0_D3_P); also elsewhere on the board
/CM5/DPHY1_P.C_N: Module302.187 (MIPI1_C_N)
/CM5/DPHY1_P.C_P: Module302.189 (MIPI1_C_P)
/CM5/DPHY1_P.D0_N: Module302.175 (MIPI1_D0_N)
/CM5/DPHY1_P.D0_P: Module302.177 (MIPI1_D0_P)
/CM5/DPHY1_P.D1_N: Module302.181 (MIPI1_D1_N)
/CM5/DPHY1_P.D1_P: Module302.183 (MIPI1_D1_P)
/CM5/DPHY1_P.D2_N: Module302.193 (MIPI1_D2_N)
/CM5/DPHY1_P.D2_P: Module302.195 (MIPI1_D2_P)
/CM5/DPHY1_P.D3_N: Module302.194 (MIPI1_D3_N)
/CM5/DPHY1_P.D3_P: Module302.196 (MIPI1_D3_P)
/CM5/EEPROM_nWP: Module301.20 (EEPROM_nWP); also elsewhere on the board
/CM5/ETH_PI.TRD0_N: Module301.10 (Ethernet_Pair0_N); also elsewhere on the board
/CM5/ETH_PI.TRD0_P: Module301.12 (Ethernet_Pair0_P); also elsewhere on the board
/CM5/ETH_PI.TRD1_N: Module301.6 (Ethernet_Pair1_N); also elsewhere on the board
/CM5/ETH_PI.TRD1_P: Module301.4 (Ethernet_Pair1_P); also elsewhere on the board
/CM5/ETH_PI.TRD2_N: Module301.9 (Ethernet_Pair2_N); also elsewhere on the board
/CM5/ETH_PI.TRD2_P: Module301.11 (Ethernet_Pair2_P); also elsewhere on the board
/CM5/ETH_PI.TRD3_N: Module301.5 (Ethernet_Pair3_N); also elsewhere on the board
/CM5/ETH_PI.TRD3_P: Module301.3 (Ethernet_Pair3_P); also elsewhere on the board
/CM5/ETH_nLED_ACTIVITY: Module301.15 (Ethernet_nLED3(3.3v)); also elsewhere on the board
/CM5/GLOBAL_EN: Module301.99 (PMIC_ENABLE)
/CM5/GPIO2: Module301.58 (GPIO2)
/CM5/GPIO3: Module301.56 (GPIO3)
/CM5/GPIO4: Module301.54 (GPIO4); also elsewhere on the board
/CM5/GPIO5: Module301.34 (GPIO5); also elsewhere on the board
/CM5/GPIO6: Module301.30 (GPIO6)
/CM5/GPIO7: Module301.37 (GPIO7)
/CM5/GPIO8: Module301.39 (GPIO8)
/CM5/GPIO9: Module301.40 (GPIO9)
/CM5/GPIO10: Module301.44 (GPIO10)
/CM5/GPIO11: Module301.38 (GPIO11)
/CM5/GPIO12: Module301.31 (GPIO12)
/CM5/GPIO13: Module301.28 (GPIO13)
/CM5/GPIO14: Module301.55 (GPIO14)
/CM5/GPIO15: Module301.51 (GPIO15)
/CM5/GPIO16: Module301.29 (GPIO16)
/CM5/GPIO17: Module301.50 (GPIO17)
/CM5/GPIO22: Module301.46 (GPIO22)
/CM5/GPIO23: Module301.47 (GPIO23)
/CM5/GPIO26: Module301.24 (GPIO26)
/CM5/GPIO_VREF: Module301.78 (GPIO_VREF(1.8v/3.3v_Input)); also elsewhere on the board
/CM5/HDMI1_CEC: Module302.149 (HDMI1_CEC)
/CM5/HDMI1_CK_N: Module302.166 (HDMI1_CLK_N)
/CM5/HDMI1_CK_P: Module302.164 (HDMI1_CLK_P)
/CM5/HDMI1_D0_N: Module302.160 (HDMI1_TX0_N)
/CM5/HDMI1_D0_P: Module302.158 (HDMI1_TX0_P)
/CM5/HDMI1_D1_N: Module302.154 (HDMI1_TX1_N)
/CM5/HDMI1_D1_P: Module302.152 (HDMI1_TX1_P)
/CM5/HDMI1_D2_N: Module302.148 (HDMI1_TX2_N)
/CM5/HDMI1_D2_P: Module302.146 (HDMI1_TX2_P)
/CM5/HDMI1_HOTPLUG: Module302.143 (HDMI1_HOTPLUG)
/CM5/HDMI1_SCL: Module302.147 (HDMI1_SCL)
/CM5/HDMI1_SDA: Module302.145 (HDMI1_SDA)
/CM5/HDMI_PI.CEC: Module302.151 (HDMI0_CEC); also elsewhere on the board
/CM5/HDMI_PI.CK_N: Module302.190 (HDMI0_CLK_N); also elsewhere on the board
/CM5/HDMI_PI.CK_P: Module302.188 (HDMI0_CLK_P); also elsewhere on the board
/CM5/HDMI_PI.D0_N: Module302.184 (HDMI0_TX0_N); also elsewhere on the board
/CM5/HDMI_PI.D0_P: Module302.182 (HDMI0_TX0_P); also elsewhere on the board
/CM5/HDMI_PI.D1_N: Module302.178 (HDMI0_TX1_N); also elsewhere on the board
/CM5/HDMI_PI.D1_P: Module302.176 (HDMI0_TX1_P); also elsewhere on the board
/CM5/HDMI_PI.D2_N: Module302.172 (HDMI0_TX2_N); also elsewhere on the board
/CM5/HDMI_PI.D2_P: Module302.170 (HDMI0_TX2_P); also elsewhere on the board
/CM5/HDMI_PI.HOTPLUG: Module302.153 (HDMI0_HOTPLUG); also elsewhere on the board
/CM5/HDMI_PI.SCL: Module302.200 (HDMI0_SCL); also elsewhere on the board
/CM5/HDMI_PI.SDA: Module302.199 (HDMI0_SDA); also elsewhere on the board
/CM5/ID_SC: Module301.35 (ID_SC)
/CM5/ID_SD: Module301.36 (ID_SD)
/CM5/MISO_GPIO19: Module301.26 (GPIO19); also elsewhere on the board
/CM5/MOSI_GPIO20: Module301.27 (GPIO20); also elsewhere on the board
/CM5/PCIE_PI.CLK_N: Module302.112 (PCIe_CLK_N); also elsewhere on the board
/CM5/PCIE_PI.CLK_P: Module302.110 (PCIe_CLK_P); also elsewhere on the board
/CM5/PCIE_PI.PWR_EN: Module302.106 (PCIE_PWR_EN); also elsewhere on the board
/CM5/PCIE_PI.RX_N: Module302.118 (PCIe_RX_N); also elsewhere on the board
/CM5/PCIE_PI.RX_P: Module302.116 (PCIe_RX_P); also elsewhere on the board
/CM5/PCIE_PI.TX_N: Module302.124 (PCIe_TX_N); also elsewhere on the board
/CM5/PCIE_PI.TX_P: Module302.122 (PCIe_TX_P); also elsewhere on the board
/CM5/PCIE_PI.nCLKREQ: Module302.102 (PCIe_nCLKREQ); also elsewhere on the board
/CM5/PCIE_PI.nRST: Module302.109 (PCIe_nRST); also elsewhere on the board
/CM5/PCIE_PI.nWAKE: Module302.104 (PCIE_nWAKE); also elsewhere on the board
/CM5/PI_nLED_PWR: Module301.95 (LED_nPWR); also elsewhere on the board
/CM5/PWM: Module301.19 (FAN_PWM); also elsewhere on the board
/CM5/PWR_BUT: Module301.92 (PWR_BUT); also elsewhere on the board
/CM5/RST_GPIO27: Module301.48 (GPIO27); also elsewhere on the board
/CM5/SCLK_GPIO21: Module301.25 (GPIO21); also elsewhere on the board
/CM5/SD_CLK: Module301.57 (SD_CLK)
/CM5/SD_CMD: Module301.62 (SD_CMD)
/CM5/SD_DAT0: Module301.63 (SD_DAT0)
/CM5/SD_DAT1: Module301.67 (SD_DAT1)
/CM5/SD_DAT2: Module301.69 (SD_DAT2)
/CM5/SD_DAT3: Module301.61 (SD_DAT3)
/CM5/SD_PWR_ON: Module301.75 (SD_PWR_ON)
/CM5/SYNC_OUT: Module301.18 (Ethernet_SYNC_OUT(3.3v))
/CM5/TACHO: Module301.16 (FAN_TACHO); also elsewhere on the board
/CM5/USB2P.D_N: Module302.136 (USB3-0-D_N); also elsewhere on the board
/CM5/USB2P.D_P: Module302.134 (USB3-0-D_P); also elsewhere on the board
/CM5/USB3-0-RX_N: Module302.128 (USB3-0-RX_N)
/CM5/USB3-0-RX_P: Module302.130 (USB3-0-RX_P)
/CM5/USB3-0-TX_N: Module302.140 (USB3-0-TX_N)
/CM5/USB3-0-TX_P: Module302.142 (USB3-0-TX_P)
/CM5/USB3-1-D_N: Module302.165 (USB3-1-D_N)
/CM5/USB3-1-D_P: Module302.163 (USB3-1-D_P)
/CM5/USB3-1-RX_N: Module302.157 (USB3-1-RX_N)
/CM5/USB3-1-RX_P: Module302.159 (USB3-1-RX_P)
/CM5/USB3-1-TX_N: Module302.169 (USB3-1-TX_N)
/CM5/USB3-1-TX_P: Module302.171 (USB3-1-TX_P)
/CM5/USBOTG_ID: Module302.101 (USB_OTG_ID)
/CM5/VBAT: Module301.76 (VBAT)
/CM5/VBUS_EN: Module302.111 (VBUS_EN); also elsewhere on the board
/CM5/WL_nDis: Module301.89 (WiFi_nDisable)
/CM5/nLED_ACTIVITY: Module301.21 (LED_nACT); also elsewhere on the board
/CM5/nLED_SPEED_100_1000: Module301.17 (Ethernet_nLED2(3.3v)); also elsewhere on the board
/CM5/nRPIBOOT: Module301.93 (nRPIBOOT); also elsewhere on the board
/SCL: Module301.80 (SCL0); also elsewhere on the board
/SDA: Module301.82 (SDA0); also elsewhere on the board
/USB_C.D_N: Module302.103 (USB2_N); also elsewhere on the board
/USB_C.D_P: Module302.105 (USB2_P); also elsewhere on the board
GND: Module301.1 (GND), Module301.2 (GND), Module301.7 (GND), Module301.8 (GND), Module301.13 (GND), Module301.14 (GND), Module301.22 (GND), Module301.23 (GND), Module301.32 (GND), Module301.33 (GND), Module301.42 (GND), Module301.43 (GND), Module301.52 (GND), Module301.53 (GND), Module301.59 (GND), Module301.60 (GND), Module301.65 (GND), Module301.66 (GND), Module301.71 (GND), Module301.74 (GND), Module301.98 (GND), Module302.107 (GND), Module302.108 (GND), Module302.113 (GND), Module302.114 (GND), Module302.119 (GND), Module302.120 (GND), Module302.125 (GND), Module302.126 (GND), Module302.131 (GND), Module302.132 (GND), Module302.137 (GND), Module302.138 (GND), Module302.144 (GND), Module302.150 (GND), Module302.155 (GND), Module302.156 (GND), Module302.161 (GND), Module302.162 (GND), Module302.167 (GND), Module302.168 (GND), Module302.173 (GND), Module302.174 (GND), Module302.179 (GND), Module302.180 (GND), Module302.185 (GND), Module302.186 (GND), Module302.191 (GND), Module302.192 (GND), Module302.197 (GND), Module302.198 (GND); also elsewhere on the board

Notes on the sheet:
CM mechanicals
[CM5]

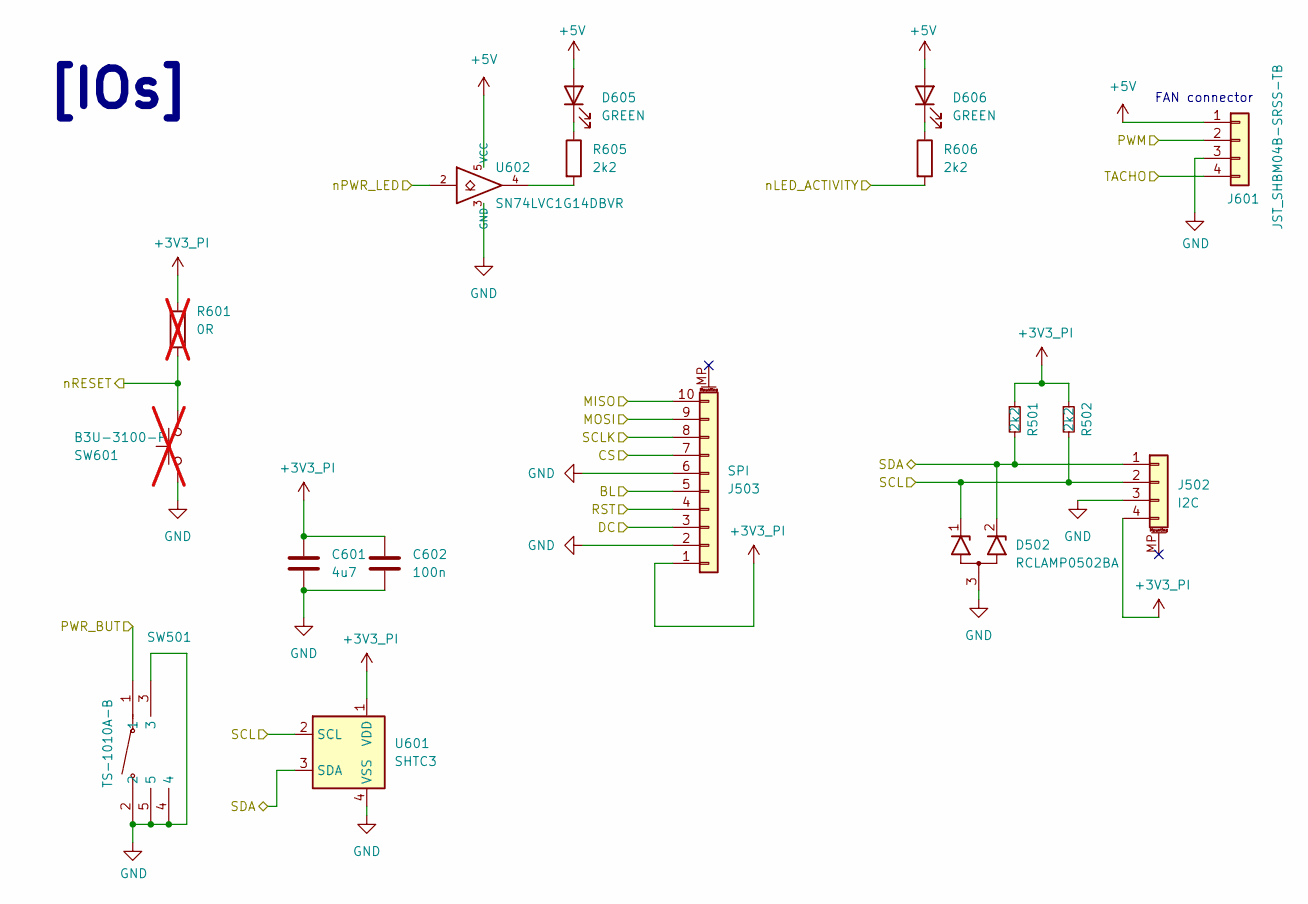
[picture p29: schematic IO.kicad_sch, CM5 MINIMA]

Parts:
C601: 4u7; C_0805_2012Metric; Part Description 4.7uF 10% 10V Ceramic Capacitor X7R 080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
C602: 100n; C_0402_1005Metric; Part Description 0.1uF 10% 16V Ceramic Capacitor X7R 040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
D502: RCLAMP0502BA; SOT-416
D605, D606: GREEN; LED-SMD_L1.7-W0.6-RD
J502: I2C; JST_SH_BM04B-SRSS-TB_1x04-1MP_P1.00mm_Vertical
J503: SPI; JST_SUR_BM10B-SURS-TF_1x10-1MP_P0.80mm_Vertical
J601: JST_SHBM04B-SRSS-TB; JST_SH_BM04B-SRSS-TB_1x04-1MP_P1.00mm_Vertical; Part Description 4 pin vertical 1mm pitch connector
R501, R502, R605, R606: 2k2; R_0402_1005Metric
R601: 0R; R_0402_1005Metric; not fitted
SW501: TS-1010A-B; SW-SMD_TS-1010A-B; LCSC Part C381059
SW601: B3U-3100-P; SW_SPST_B3U-3100P-B; not fitted
U601: SHTC3; Sensirion_DFN-4-1EP_2x2mm_P1mm_EP0.7x1.6mm
U602: SN74LVC1G14DBVR; SOT-353_SC-70-5; Part Description Buffer, Non-Inverting 1 Element 1 Bit p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

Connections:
+3V3_PI: C601.1, C602.1, J502.4, J503.1, R501.1, R502.1, R601.1, U601.1 (VDD); also elsewhere on the board
+5V: D605.2 (A), D606.2 (A), J601.1, U602.5 (VCC); also elsewhere on the board
/CM5/BL_GPIO18: J503.5; also elsewhere on the board
/CM5/CS_GPIO24: J503.7; also elsewhere on the board
/CM5/DC_GPI25: J503.3; also elsewhere on the board
/CM5/MISO_GPIO19: J503.10; also elsewhere on the board
/CM5/MOSI_GPIO20: J503.9; also elsewhere on the board
/CM5/PI_nLED_PWR: U602.2; also elsewhere on the board
/CM5/PWM: J601.2; also elsewhere on the board
/CM5/PWR_BUT: SW501.1; also elsewhere on the board
/CM5/RST_GPIO27: J503.4; also elsewhere on the board
/CM5/SCLK_GPIO21: J503.8; also elsewhere on the board
/CM5/TACHO: J601.4; also elsewhere on the board
/CM5/nLED_ACTIVITY: R606.2; also elsewhere on the board
/SCL: D502.1 (K1), J502.2, R502.2, U601.2 (SCL); also elsewhere on the board
/SDA: D502.2 (K2), J502.1, R501.2, U601.3 (SDA); also elsewhere on the board
GND: C601.2, C602.2, D502.3 (A), J502.3, J503.2, J503.6, J601.3, SW501.2, SW501.3, SW501.4, SW501.5, SW601.2, U601.4 (VSS), U602.3 (GND); also elsewhere on the board
unnamed: D605.1 (K), R605.1
unnamed: D606.1 (K), R606.1
unnamed: R601.2, SW601.1
unnamed: R605.2, U602.4

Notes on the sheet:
[IOs]
FAN connector

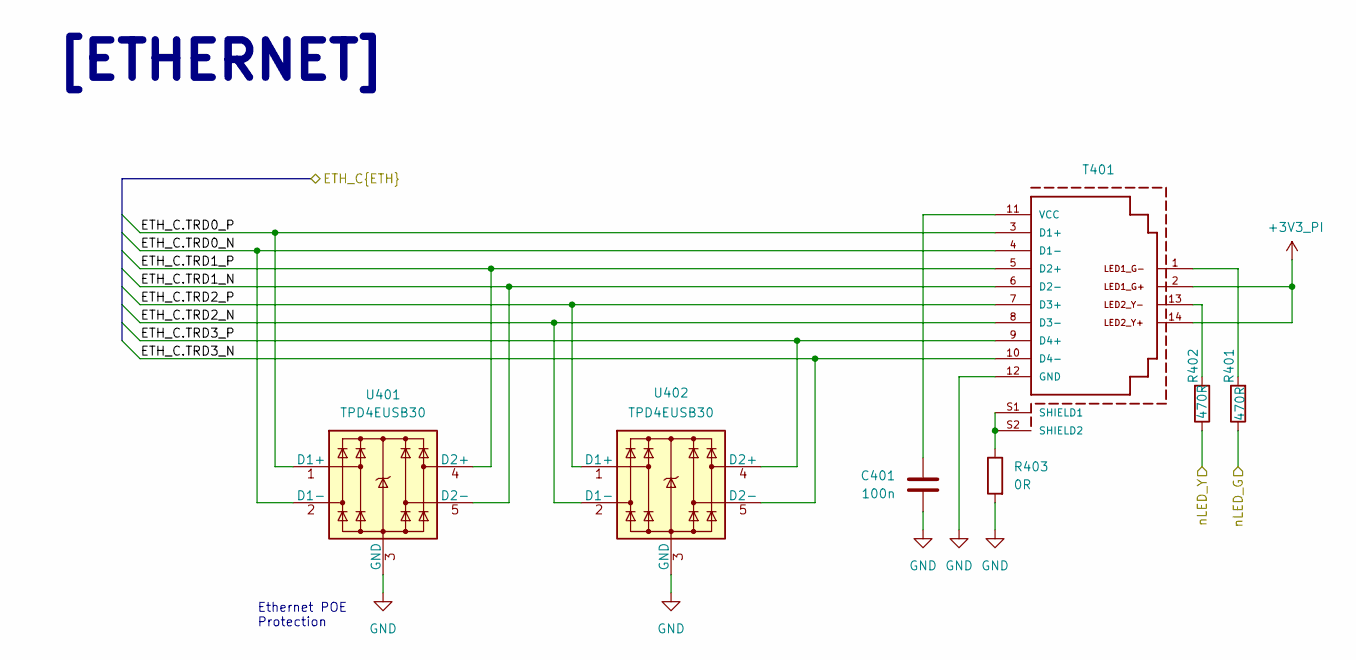
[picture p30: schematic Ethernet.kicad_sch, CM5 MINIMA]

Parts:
C401: 100n; C_0402_1005Metric; Part Description 0.1uF 10% 16V Ceramic Capacitor X7R 040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
R401, R402: 470R; R_0402_1005Metric
R403: 0R; R_0402_1005Metric
T401: 7498111120AR; PART-NUMBER 7498111120AR
U401, U402: TPD4EUSB30; USON-10_2.5x1.0mm_P0.5mm; Part Description Quad TVS diode for high speed signals (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

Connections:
+3V3_PI: T401.2, T401.14; also elsewhere on the board
/CM5/ETH_PI.TRD0_N: T401.4 (D1-), U401.2 (D1-), U401.9; also elsewhere on the board
/CM5/ETH_PI.TRD0_P: T401.3 (D1+), U401.1 (D1+), U401.10; also elsewhere on the board
/CM5/ETH_PI.TRD1_N: T401.6 (D2-), U401.5 (D2-), U401.6; also elsewhere on the board
/CM5/ETH_PI.TRD1_P: T401.5 (D2+), U401.4 (D2+), U401.7; also elsewhere on the board
/CM5/ETH_PI.TRD2_N: T401.8 (D3-), U402.2 (D1-), U402.9; also elsewhere on the board
/CM5/ETH_PI.TRD2_P: T401.7 (D3+), U402.1 (D1+), U402.10; also elsewhere on the board
/CM5/ETH_PI.TRD3_N: T401.10 (D4-), U402.5 (D2-), U402.6; also elsewhere on the board
/CM5/ETH_PI.TRD3_P: T401.9 (D4+), U402.4 (D2+), U402.7; also elsewhere on the board
/CM5/ETH_nLED_ACTIVITY: R401.1; also elsewhere on the board
/CM5/nLED_SPEED_100_1000: R402.1; also elsewhere on the board
GND: C401.2, R403.2, T401.12 (GND), U401.3 (GND), U401.8 (GND), U402.3 (GND), U402.8 (GND); also elsewhere on the board
unnamed: R401.2, T401.1
unnamed: R402.2, T401.13
unnamed: R403.1, T401.S1 (SHIELD1), T401.S2 (SHIELD2)
unnamed: C401.1, T401.11 (VCC)

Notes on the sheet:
[ETHERNET]
Ethernet POE Protection

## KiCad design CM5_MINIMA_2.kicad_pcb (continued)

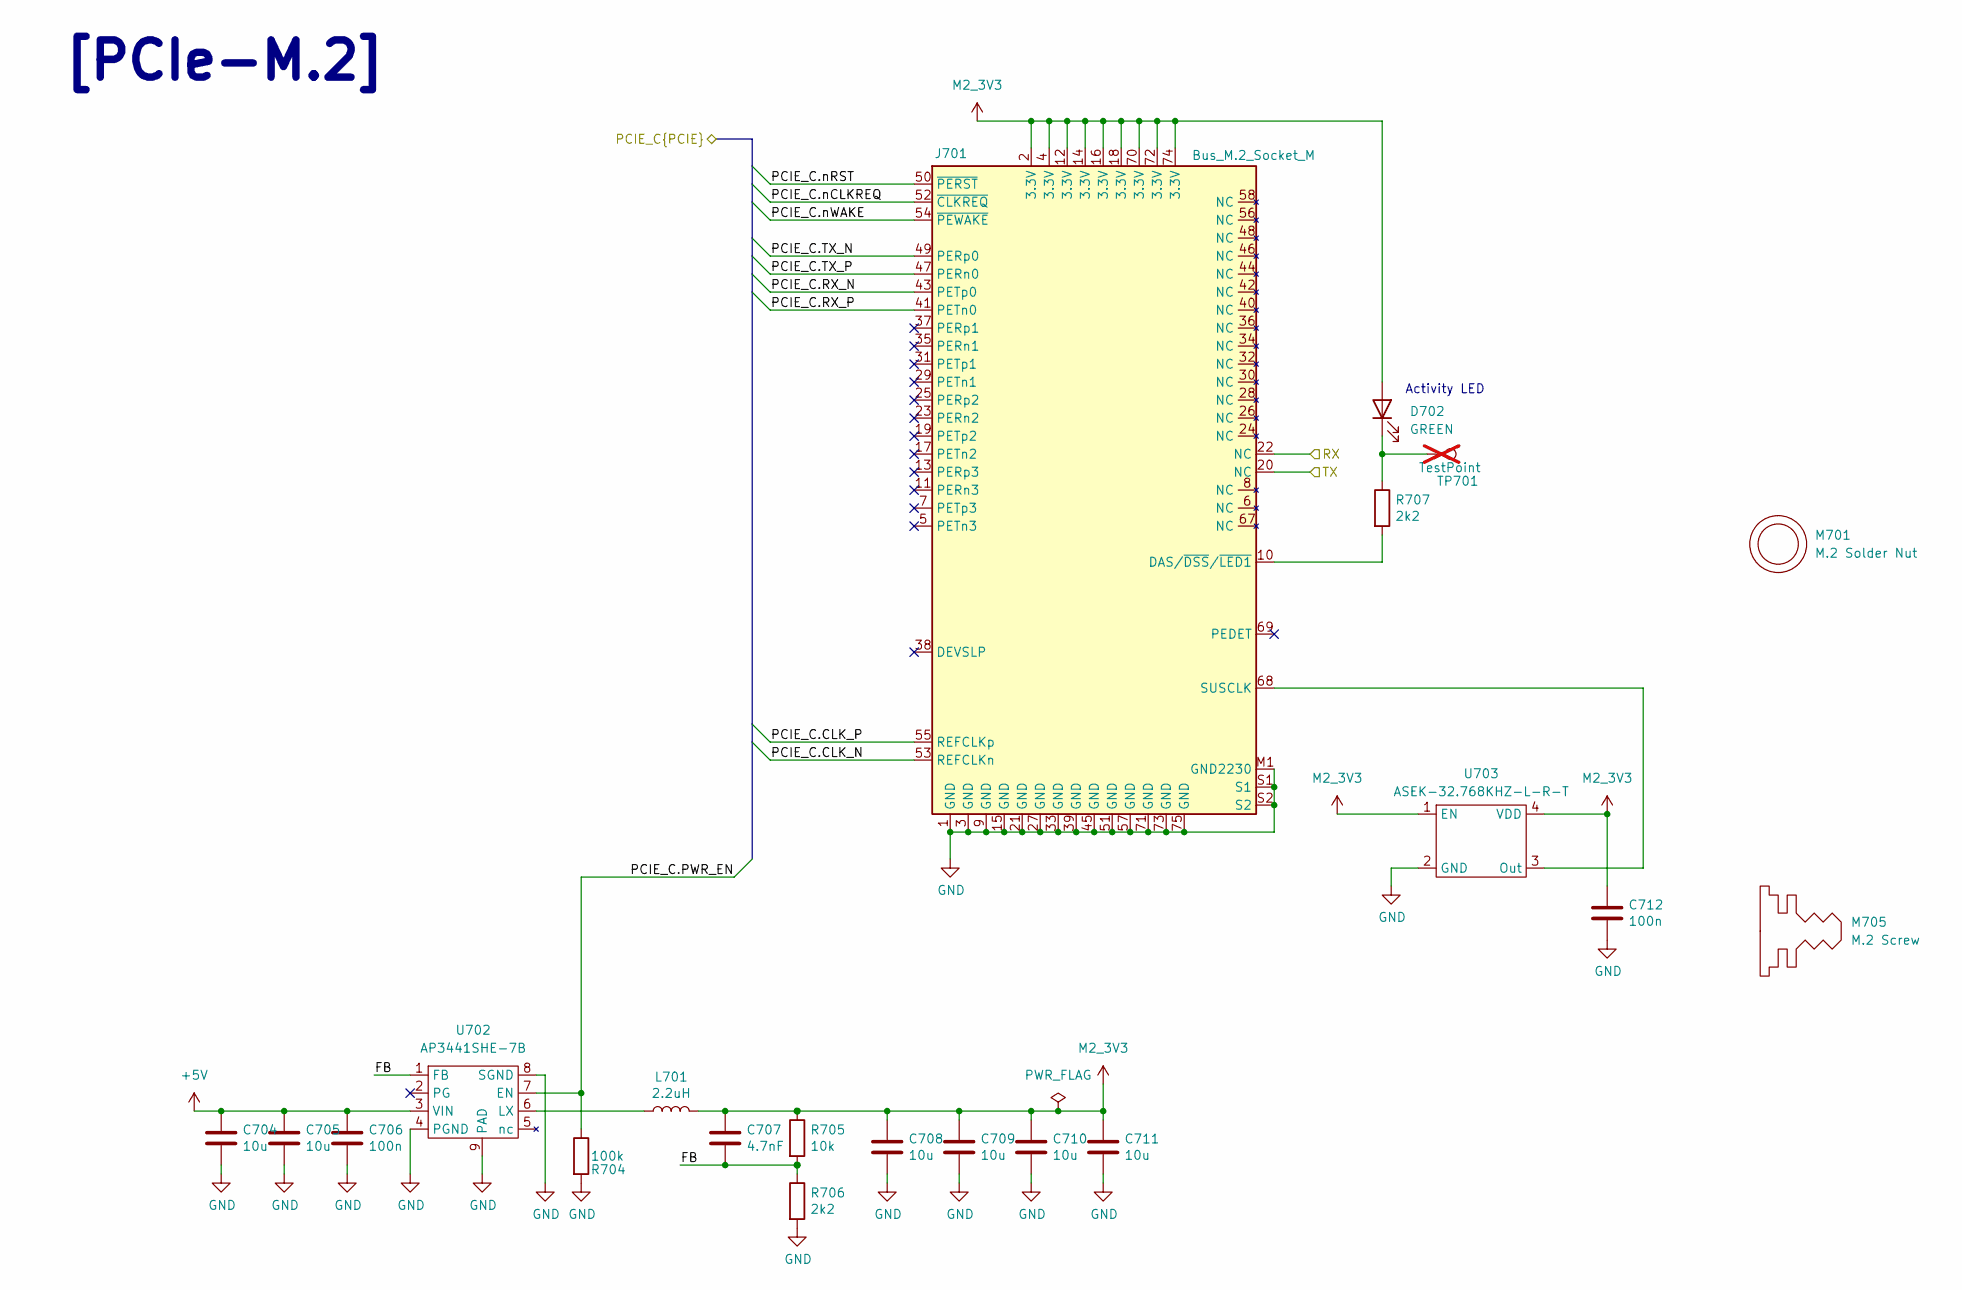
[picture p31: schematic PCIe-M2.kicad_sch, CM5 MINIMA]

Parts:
C704, C705, C708, C709, C710, C711: 10u; C_0805_2012Metric; Part Description 10uF 10% 10V Ceramic Capacitor X7R 0805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
C706, C712: 100n; C_0402_1005Metric; Part Description 0.1uF 10% 16V Ceramic Capacitor X7R 040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
C707: 4.7nF; C_0402_1005Metric; Part Description 4.7nF capacitor 0402
D702: GREEN; LED-SMD_L1.7-W0.6-RD
J701: Bus_M.2_Socket_M; M.2 M Key socket 2230; Part Description M.2 M Key connector
L701: 2.2uH; L_Bourns_SRP5030CC; Part Description Inductor, SMT, 2520, 2u2, IRMS=7A, ISAT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
M701: M.2 Solder Nut; MountingHole_3.78mm_M2_Pad_TopOnly; Part Description Solder nut for M.2 slot
M705: M.2 Screw; Part Description M.2 Screw
R704: 100k; R_0402_1005Metric
R705: 10k; R_0402_1005Metric
R706: 2k2; R_0402_1005Metric
R707: 2k2; R_0402_1005Metric; Part Description Resistor 1K M1005 1% 63mW
TP701: TestPoint; TestPoint_Pad_2.0x2.0mm; Part Description Test point; not fitted
U702: AP3441SHE-7B; DFN-8-1EP_2x2mm_P0.5mm_EP1.05x1.75mm; Part Description 3A DC-DC converter
U703: ASEK-32.768KHZ-L-R-T; Crystal_SMD_3225-4Pin_3.2x2.5mm; Part Description 32KHz Xtal oscilator

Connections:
+5V: C704.1, C705.1, C706.1, U702.3 (VIN); also elsewhere on the board
/CM5/PCIE_PI.CLK_N: J701.53 (REFCLKn); also elsewhere on the board
/CM5/PCIE_PI.CLK_P: J701.55 (REFCLKp); also elsewhere on the board
/CM5/PCIE_PI.PWR_EN: R704.1, U702.7 (EN); also elsewhere on the board
/CM5/PCIE_PI.RX_N: J701.43 (PETp0); also elsewhere on the board
/CM5/PCIE_PI.RX_P: J701.41 (PETn0); also elsewhere on the board
/CM5/PCIE_PI.TX_N: J701.49 (PERp0); also elsewhere on the board
/CM5/PCIE_PI.TX_P: J701.47 (PERn0); also elsewhere on the board
/CM5/PCIE_PI.nCLKREQ: J701.52 (~CLKREQ); also elsewhere on the board
/CM5/PCIE_PI.nRST: J701.50 (~PERST); also elsewhere on the board
/CM5/PCIE_PI.nWAKE: J701.54 (~PEWAKE); also elsewhere on the board
/PCIe-M2/FB: C707.2, R705.2, R706.1, U702.1 (FB)
/PCIe-M2/RX: J701.22 (NC); also elsewhere on the board
/PCIe-M2/TX: J701.20 (NC); also elsewhere on the board
GND: C704.2, C705.2, C706.2, C708.2, C709.2, C710.2, C711.2, C712.2, J701.1 (GND), J701.3 (GND), J701.9 (GND), J701.15 (GND), J701.21 (GND), J701.27 (GND), J701.33 (GND), J701.39 (GND), J701.45 (GND), J701.51 (GND), J701.57 (GND), J701.71 (GND), J701.73 (GND), J701.75 (GND), J701.M1 (GND2230), J701.S1, J701.S2, R704.2, R706.2, U702.4 (PGND), U702.8 (SGND), U702.9 (PAD), U703.2 (GND); also elsewhere on the board
M2_3V3: C707.1, C708.1, C709.1, C710.1, C711.1, C712.1, D702.2 (A), J701.2 (3.3V), J701.4 (3.3V), J701.12 (3.3V), J701.14 (3.3V), J701.16 (3.3V), J701.18 (3.3V), J701.70 (3.3V), J701.72 (3.3V), J701.74 (3.3V), L701.2, R705.1, U703.1 (EN), U703.4 (VDD)
unnamed: D702.1 (K), R707.1, TP701.1
unnamed: J701.10 (DAS/~DSS/~LED1), R707.2
unnamed: J701.68 (SUSCLK), U703.3 (Out)
unnamed: L701.1, U702.6 (LX)

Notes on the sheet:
[PCIe-M.2]
Activity LED

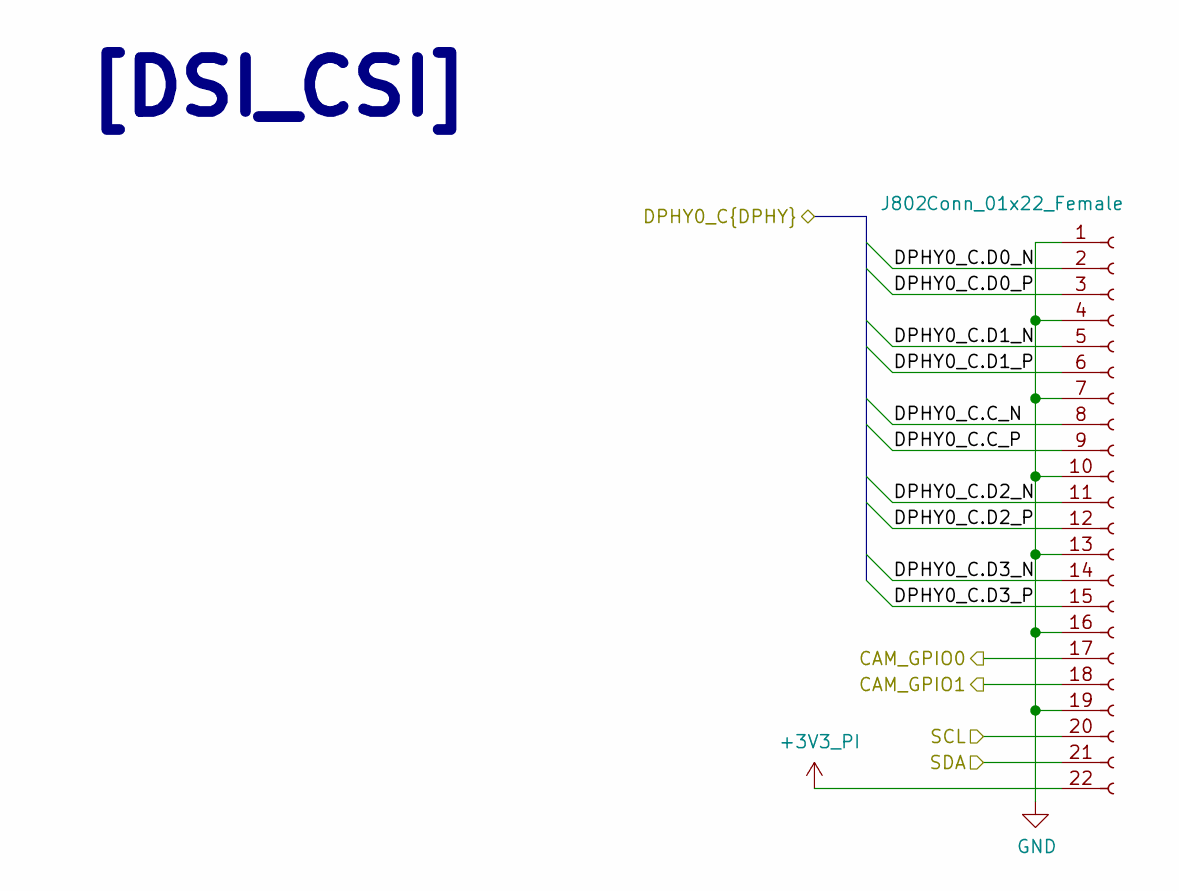
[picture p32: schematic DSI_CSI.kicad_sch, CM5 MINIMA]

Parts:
J802: Conn_01x22_Female; Hirose_FH12-22S-0.5SH_1x22-1MP_P0.50mm_Horizontal; Part Description 22 Position FFC, FPC Connector Contacts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

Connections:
+3V3_PI: J802.22; also elsewhere on the board
/CM5/CAM_GPIO0: J802.17; also elsewhere on the board
/CM5/CAM_GPIO1: J802.18; also elsewhere on the board
/CM5/DPHY0_P.C_N: J802.8; also elsewhere on the board
/CM5/DPHY0_P.C_P: J802.9; also elsewhere on the board
/CM5/DPHY0_P.D0_N: J802.2; also elsewhere on the board
/CM5/DPHY0_P.D0_P: J802.3; also elsewhere on the board
/CM5/DPHY0_P.D1_N: J802.5; also elsewhere on the board
/CM5/DPHY0_P.D1_P: J802.6; also elsewhere on the board
/CM5/DPHY0_P.D2_N: J802.11; also elsewhere on the board
/CM5/DPHY0_P.D2_P: J802.12; also elsewhere on the board
/CM5/DPHY0_P.D3_N: J802.14; also elsewhere on the board
/CM5/DPHY0_P.D3_P: J802.15; also elsewhere on the board
/SCL: J802.20; also elsewhere on the board
/SDA: J802.21; also elsewhere on the board
GND: J802.1, J802.4, J802.7, J802.10, J802.13, J802.16, J802.19; also elsewhere on the board

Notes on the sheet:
[DSI_CSI]

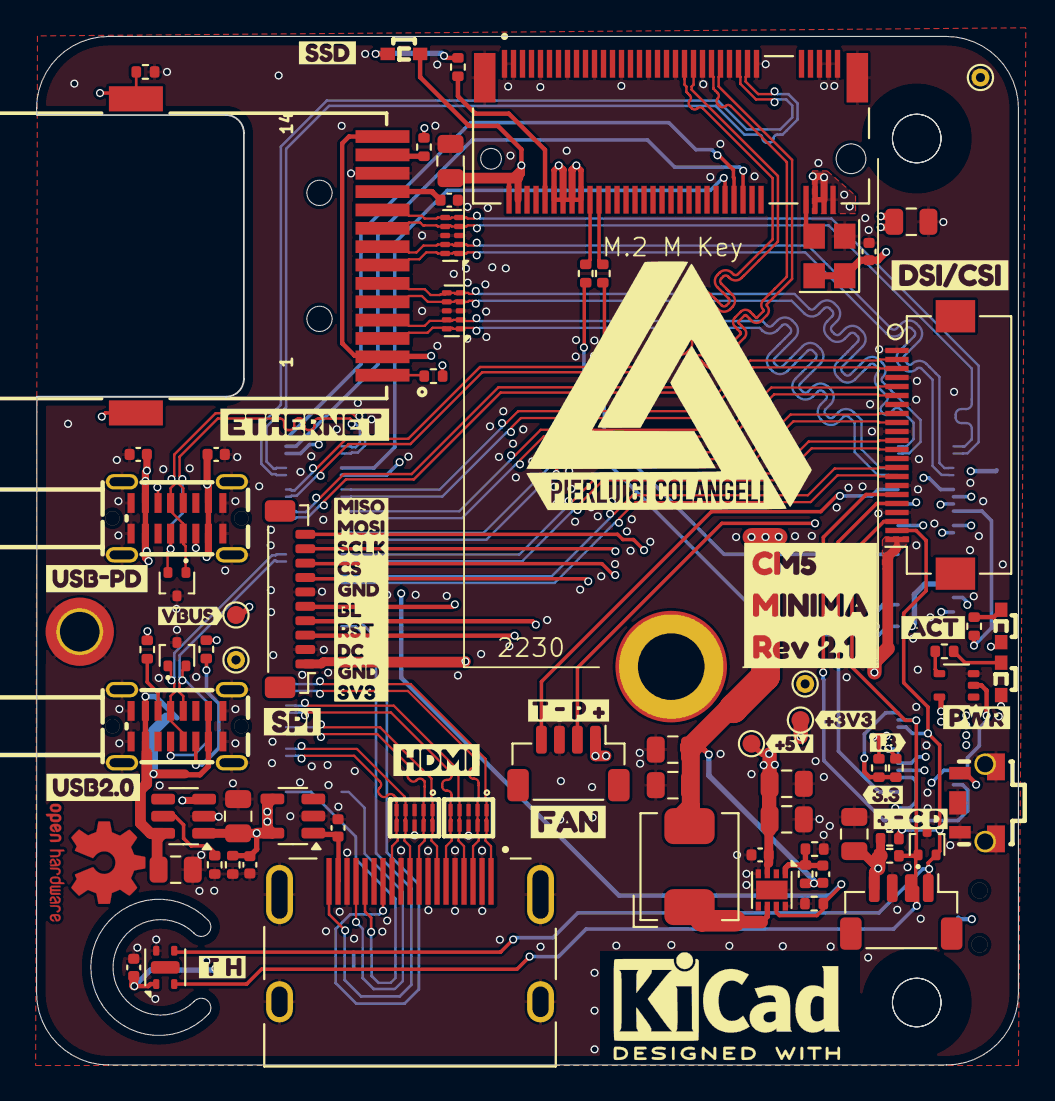
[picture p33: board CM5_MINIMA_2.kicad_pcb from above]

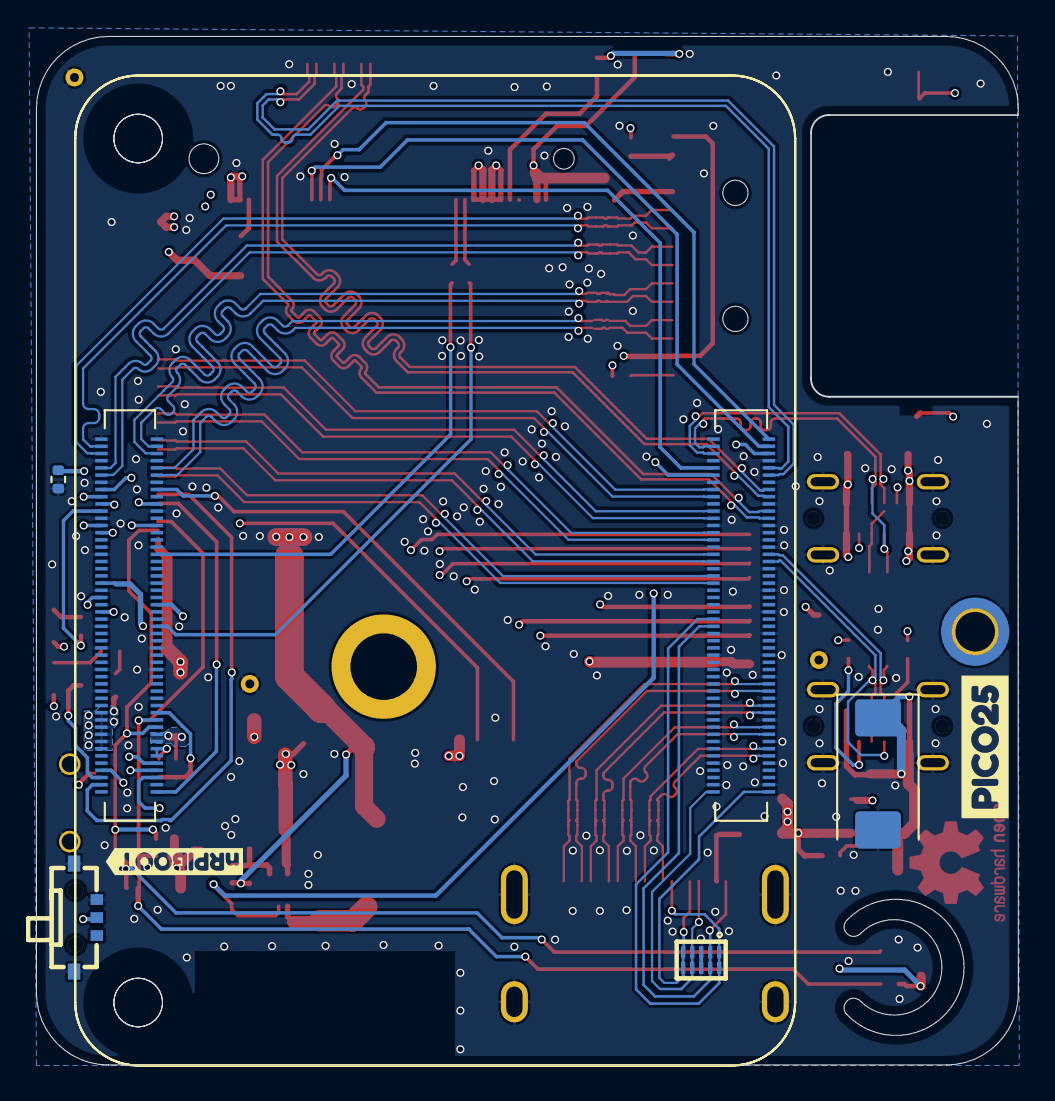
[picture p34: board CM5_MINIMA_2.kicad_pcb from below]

Board: 6 copper layers, 54.6 x 57.1 mm, 100 parts (8 on the bottom side), 94 nets.

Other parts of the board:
kibuzzard-675DA838: G***; kibuzzard-675DA838
kibuzzard-675DA850: G***; kibuzzard-675DA850
kibuzzard-675DA866: G***; kibuzzard-675DA866
kibuzzard-675EDCA4: G***; kibuzzard-675EDCA4
kibuzzard-675EDCB9: G***; kibuzzard-675EDCB9
kibuzzard-679BB153: G***; kibuzzard-679BB153
kibuzzard-6772D327: G***; kibuzzard-6772D327
kibuzzard-6772DA33: G***; kibuzzard-6772DA33
kibuzzard-6773B9B9: G***; kibuzzard-6773B9B9
kibuzzard-6773B9CA: G***; kibuzzard-6773B9CA
kibuzzard-6773B9F7: G***; kibuzzard-6773B9F7
kibuzzard-6773BA43: G***; kibuzzard-6773BA43
kibuzzard-6773BA89: G***; kibuzzard-6773BA89
kibuzzard-6773C2D7: G***; kibuzzard-6773C2D7
kibuzzard-6773C222: G***; kibuzzard-6773C222
kibuzzard-6773C376: G***; kibuzzard-6773C376
kibuzzard-6773CC4D: G***; kibuzzard-6773CC4D
kibuzzard-6773CC39: G***; kibuzzard-6773CC39
kibuzzard-6775AD68: G***; kibuzzard-6775AD68
kibuzzard-67758845: G***; kibuzzard-67758845
kibuzzard-67758943: G***; kibuzzard-67758943
kibuzzard-67795592: G***; kibuzzard-67795592

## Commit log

2025-01-04 power symbols
    [CM5.kicad_sch, CM5_MINIMA_2.kicad_pcb, CM5_MINIMA_2.kicad_sch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]
2025-01-04 pcie signal corrected
    [CM5_MINIMA_2.kicad_pcb]
2025-01-04 drc ok
    [CM5_MINIMA_2.kicad_pcb]
2025-01-04 changed i2c connector and nrpiboot
    [CM5.kicad_sch, CM5_MINIMA_2.kicad_pcb, CM5_MINIMA_2.kicad_sch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]
2025-01-04 m2 vin increased size
    [CM5_MINIMA_2.kicad_pcb]
2025-01-04 esd HDMI complete
    [CM5_MINIMA_2.kicad_pcb, HDMI.kicad_sch, IO.kicad_sch]
2025-01-04 more GND vias
    [CM5_MINIMA_2.kicad_pcb]
2025-01-04 BOM ok
    [CM5_MINIMA_2-CuBottom.gbr, CM5_MINIMA_2-CuIn1.gbr, CM5_MINIMA_2-CuIn2.gbr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]
2025-01-04 pcbway prod files created
    [CM5_MINIMA_2.kicad_pcb]
2025-01-04 pcb pic
2025-01-06 HDMI impedance 100ohm fix reroute
    [CM5_MINIMA_2.kicad_pcb]
2025-01-06 pcbway redraw
2025-01-14 swap TX RX M2
    [CM5.kicad_sch, CM5_MINIMA_2.kicad_pcb, CM5_MINIMA_2.kicad_sch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]
2025-01-17 fixed PN on M.2 connector
2025-01-30 rework for JLC
    [CM5_MINIMA_2-CuBottom.gbr, CM5_MINIMA_2-CuIn1.gbr, CM5_MINIMA_2-CuIn2.gbr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]
2025-02-13 jlc bom polishing
    [CM5_MINIMA_2-CuBottom.gbr, CM5_MINIMA_2-CuIn1.gbr, CM5_MINIMA_2-CuIn2.gbr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]
2025-03-22 3d models updated
    [CM5_MINIMA_2.kicad_pcb]
2025-03-22 updated semantic versioning
    [CM5.kicad_sch, CM5_MINIMA_2.kicad_sch, DSI_CSI.kicad_sch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]
2025-03-28 check BOM
    [CM5_MINIMA_2-CuBottom.gbr, CM5_MINIMA_2-CuIn1.gbr, CM5_MINIMA_2-CuIn2.gbr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]

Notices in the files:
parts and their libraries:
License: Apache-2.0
